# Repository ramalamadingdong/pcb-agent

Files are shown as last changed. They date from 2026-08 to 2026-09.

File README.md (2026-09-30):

# pcb-agent

Design a circuit board end to end with an agent. Parts, netlist, placement,
routing, gerbers a fab will build. You review, it does the work.

<p align="center">
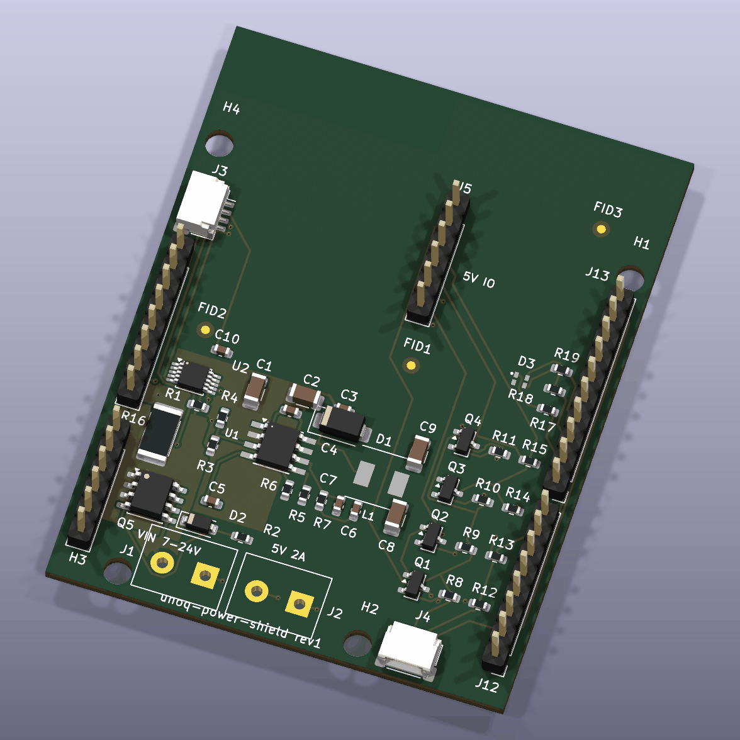
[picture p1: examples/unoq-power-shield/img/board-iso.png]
3D render of the example board: a UNO Q power and I/O shield, 49 components on four layers
  
</p>

<p align="center"><em>The example board —
<a href="examples/unoq-power-shield">examples/unoq-power-shield</a>, 49 components
on four layers, routed to 0 unconnected and 0 clearance violations. A KiCad render
of the design files in this repo; <strong>no physical board has been
fabricated</strong>.</em></p>

The method: **the design lives in a CSV, not in KiCad.** One row per pin.
Scripts build the schematic and the board from it. Nothing in the KiCad files
is edited by hand — to change the circuit you edit a row and rebuild. Then
five levels of checking, the last of which parses the exported gerbers,
because the gerbers are what the factory builds.

Written up in full at
[mouro.ai/blog/pcb-design-with-ai](https://mouro.ai/blog/pcb-design-with-ai/)
— why the CSV is the source of truth, the tool behaviour each pass exists
to survive, and what the example board cost to finish.

**New here? [docs/end-to-end.md](docs/end-to-end.md)** is the whole path in
one page: install, prove the toolchain on the example, then your own board
from an idea to a fab package.

## Status: passes landed, example board unproven

The build passes are in `scripts/build/` and the whole pipeline runs end to
end against the example board: netlist → schematic (clean round-trip diff) →
board → netclasses → floorplan → holes → zones/fanout → freerouting →
completion → fab export → checker. As of 2026-08-30 the example has passed
its pre-order gates — **0 unconnected, 0 clearance violations** across 5
identical DRC runs, `validate_gerbers` 14/0, `check_placement` 5/0, ERC
clean, every residual DRC item explained in its `rev-1-plan.md` ledger — but
**no physical board has been fabricated yet**. Until one comes back and powers on, treat
`examples/unoq-power-shield` as a pipeline exercise, not a verified
reference design.

**2026-09-30: three defects found and fixed, example rebuilt.** New gates
caught three real defects that the earlier gates had passed:

- **J4 (Qwiic) was rotated 180°.** Its socket opened into the board.
  `check_placement` now derives which way a connector faces from its
  rotation. J4 is at 0° now.
- **16 pads on eight rotated passives lay along the part axis.**
  `fix_pad_angles --check` now gates on it.
- **`finish_routes` laid redundant copper on already-routed nets.** Its
  connectivity model never joined a segment's two ends. That is fixed, and
  roughly 200 redundant segments and 69 vias are gone.

The example was rebuilt from `netlist.csv` in the pinned container.
`make check` passes every gate:

- ERC: 0 errors.
- Pad angles: all correct.
- DRC ×5: 13 errors, all in the `[[drc.accept]]` ledger with reasons, 0
  unconnected, identical in every run.
- `check_placement`: 11/0.
- `validate_gerbers`: 15/0, including the IPC-D-356 netlist against
  `netlist.csv`, 159/159 pins.

It is still **unfabricated**. See `rev-1-plan.md` for what remains at order
time.

If you want only the fab-output checker, it stands alone with no dependencies
at [gerber-check](https://github.com/ramalamadingdong/gerber-check).

Platform honesty: developed and verified on Linux (WSL) — the container
path, the clean-box doctor advice, and the whole pipeline. **macOS is
untested**: `doctor.py`'s KiCad.app python path was written from
documentation, not a Mac, and is the most likely thing to be wrong. If you
hit it, an issue with your `doctor.py` output is gold.

## Setup

```bash
git clone https://github.com/ramalamadingdong/pcb-agent && cd pcb-agent
python3 scripts/doctor.py
```

The doctor names every missing piece and the fix for your OS. Five things have
to line up — KiCad (9 or 10, **matching the major your boards use**: a KiCad 9
pcbnew returns None loading a KiCad 10 board, no error), KiCad's bundled
Python, a JVM matching your Freerouting, the Freerouting jar, and `uv` — and
each fails in a way that wastes an afternoon if you don't know what you're
looking at.

### Or: the container

The headless stages run in a container instead, so KiCad, Java and
Freerouting never need installing by hand:

```bash
make setup     # builds the pcb-agent image; fetches the pinned Freerouting
               # jar to tools/ for native runs, checksum-verified
make doctor    # reports what the container satisfies
make build route export check   # run in-container automatically when the
                                # image exists (BOARD_DIR picks the board)
```

`./run.sh <cmd>` runs any command in the container with the repo mounted at
/work, as your uid/gid. You still install KiCad natively to *look* at the
board — the container has no GUI (the one X11 artifact inside is xvfb, a
virtual framebuffer that exists solely because Freerouting 1.9.0 asks for a
screen size it never uses). The base image is digest-pinned (`KICAD_BASE` in
the Makefile) and must match your native KiCad major; the doctor warns on
drift. kicad/kicad images are linux/amd64 — Apple Silicon runs them under
emulation.

Then, in Claude Code:

```
/plugin marketplace add aklofas/kicad-happy
/plugin install kicad-happy@kicad-happy
```

Eleven KiCad skills by Andrew Klofas — datasheet extraction, EMC, SPICE,
sourcing from DigiKey, Mouser, LCSC and element14, fab prep for JLCPCB and
PCBWay. MIT. This is the install that matters most.

## Use

```
/new-board     an idea, interviewed into a cited plan and a netlist.csv
/build         netlist.csv -> schematic -> board -> placement -> zones -> silk
/route         snapshot -> Freerouting -> DRC x5 -> gerbers
/check         ERC, pad angles, DRC x5, placement, and the fab package, all gated
/improve-placement   look at where routing got stuck, try floorplan edits,
               keep only what a rebuild + re-route measures as better
/doctor        is this machine able to run any of it
```

`/new-board` stops twice for your sign-off: once after the interview, once
before it writes the netlist. Those stops are the safety story. An
idea-to-board prompt with no stops will produce sixty confident rows of
hallucinated pin numbers and you won't find out until the boards arrive.

The whole path, install to fab package:
[docs/end-to-end.md](docs/end-to-end.md). From netlist to fab package for
your own design, in more detail:
[docs/your-own-board.md](docs/your-own-board.md) — the board.toml sections,
the placement loop, and the traps this repo already paid for.

## What's here and what isn't

Working now:

- **`scripts/validate_gerbers.py`** — the level-4 checker. Reads exported
  gerbers and drill files as text. No dependencies, no install, doesn't need
  KiCad. Runs on any fab package from any tool. See below.
- **`scripts/build/check_placement.py`** — the board-level checker, and the
  other half of `make check`. Two things the gerber checker structurally
  cannot see: whether every `[[connectors]]` part can actually be **plugged
  into** (mating face reaches the outline, corridor for plug and cable clear —
  mounting holes inflated to the *screw head*, which is the thing actually in
  the way and which no courtyard in the file describes), and copper in a
  keepout named by object (`R12 pad 2`, `via GND at 41.20,18.05`) instead of
  by aperture. Runs in about a second off the board file, so a floorplan
  mistake surfaces while the floorplan is still what you are editing, not
  fifteen minutes later in the fab package.
- **`scripts/build/drc_sample.py`, `erc_check.py`**: levels 1 and 2 as
  gates, not reports. DRC runs 5×, and anything unexplained in any run fails.
  The explanations live in `board.toml` as `[[drc.accept]]` entries, each
  with its reason. An entry that stops matching fails too. Connectivity
  parity (the board's nets against the schematic) is gated even though KiCad
  ships it as a warning.
- **`check_netlist`** in `validate_gerbers.py`: level 0 on what ships. The
  export includes an IPC-D-356 netlist (the file a fab's electrical test
  probes against), and the checker holds it to `netlist.csv` pin by pin.
- **`scripts/build/render_review.py`** (`make render`): a PNG per copper layer
  with the ratsnest in red and completion-pass copper in orange, for level 3
  and `/improve-placement`. **`score_route.py`** (`make score`): one
  comparable score for a routed board, measured, never read from the
  router's log.
- **`scripts/doctor.py`**: environment preflight.
- **`CLAUDE.md`** — the rules. This is what keeps an agent from undoing the
  work: don't edit board files, fixes go in the pipeline, every pass
  idempotent, don't trust a tool's self-report, get the document.
- **`commands/`**: the six slash commands.
- **`templates/`** — `netlist.csv` schema and a commented `board.toml`.

Also here now:

- **`scripts/build/`** — the build passes, ported from the pipeline that
  shipped real boards. They encode specific tool behaviour discovered by
  getting boards back broken — `repair_pads` restoring rotation as well as
  position, the net-table assertion after every board write, the
  four-spacing fanout check, `silk_finish` repositioning every refdes —
  with the comments explaining why each guard exists.

Not here yet:

- **An example board that has been powered on.** `examples/unoq-power-shield`
  has a cited plan and netlist, but until one is built and brought up it is a
  reference design nobody has verified.

## The gerber checker on its own

Useful even if you never adopt the rest:

```bash
python3 scripts/validate_gerbers.py --init      # writes board.toml
python3 scripts/validate_gerbers.py ./fab/
```

Catches what passes ERC, passes DRC, passes every fab export, and still ships
a broken board:

| Check | Why nothing else sees it |
| --- | --- |
| Signal traces on a layer you declared a plane | DRC doesn't know it's a plane. Breaks the reference for anything routed over it. |
| Power nets at default trace width | Generated netclass patterns (`VCC*`, `VDD*`, `+*V`) match none of the usual net names. Nothing errors, the traces just come out thin. |
| Missing mounting holes | Not netlist objects. Nothing emits them unless you write the pass. |
| Silkscreen past the board outline | The fab clips it. Boards print bare. |
| Fiducials missing, collinear, or in a keepout | Keepout rules ban pours, tracks and vias — not pads. |
| Too few thermal vias under an exposed pad | No rule covers "enough". |
| RF trace over budget | Nothing measures it. |

Rules you don't configure report `SKIP`, not `PASS`. A check you haven't
written isn't a check that passed.

Export with X2 attributes on — net names and fiducial tags ride in those, and
without them the net-aware checks go blind.

## Scope

This gets you to a package a fab will build and a written reason behind every
choice in it. Respins in hours instead of days, because the fixes are in code.

It doesn't replace bring-up. Done and clean and fabricated isn't the same as
working.

## Credit

- [kicad-happy](https://github.com/aklofas/kicad-happy) — Andrew Klofas, MIT
- [kicad-tools](https://github.com/rjwalters/kicad-tools) — RJ Walters, MIT
- [Freerouting](https://github.com/freerouting/freerouting)
- [KiCad-AI-Assistant](https://github.com/paul356/KiCad-AI-Assistant) (MIT,
  © 2025 Lama Al Rajih): `render_review.py`'s per-layer panels and MST
  ratsnest follow the approach of its board renderer. The ideas are
  borrowed; no code was copied.
- [KiCad](https://www.kicad.org/)

GPL-3.0 — the build passes import `pcbnew`, which is GPL-3.0, and now that
they've landed the repo follows.
[gerber-check](https://github.com/ramalamadingdong/gerber-check) is pure
stdlib text parsing, links nothing, and stays MIT.

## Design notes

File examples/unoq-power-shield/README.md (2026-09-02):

# UNO Q power & I/O demo shield

<table>
<tr>
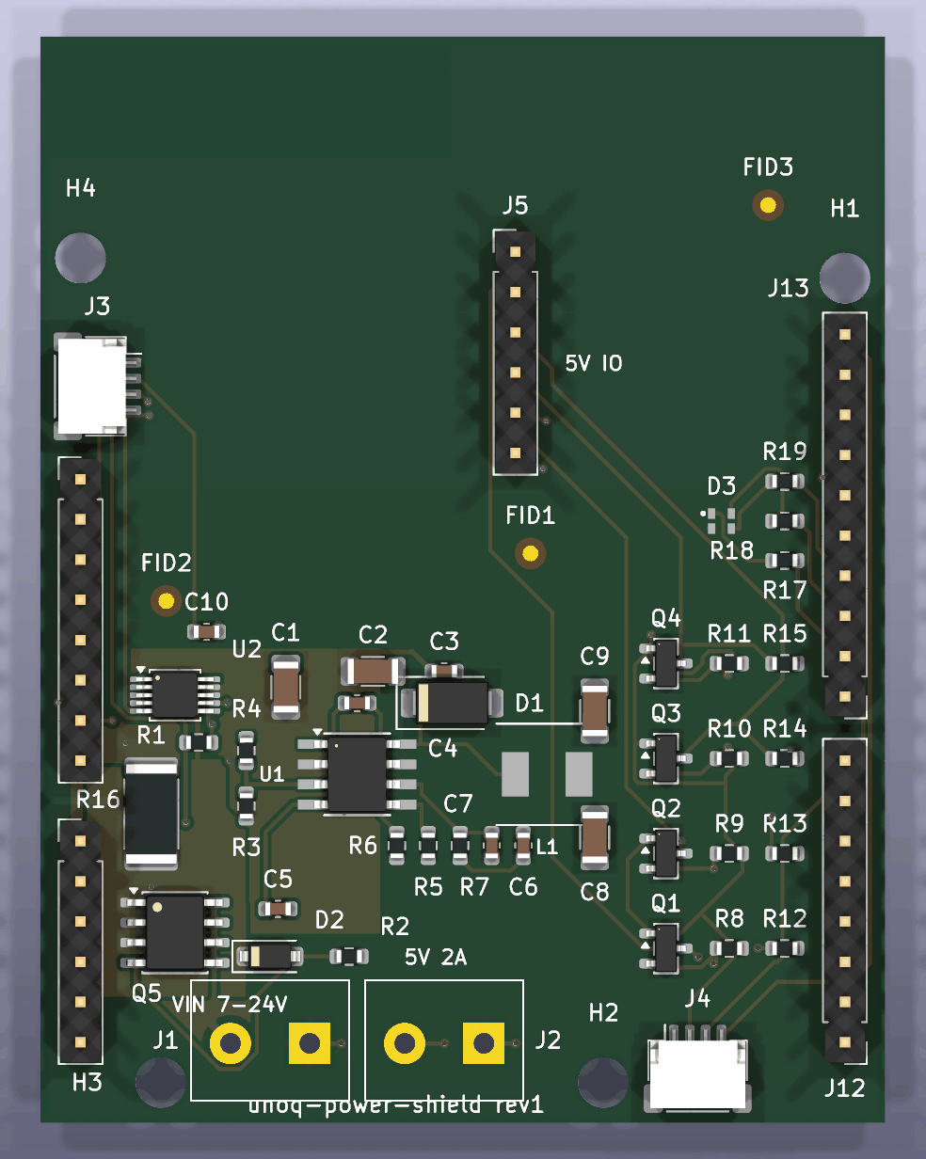
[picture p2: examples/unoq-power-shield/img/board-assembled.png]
Render of the board with every component placed
<td width="50%"></td>
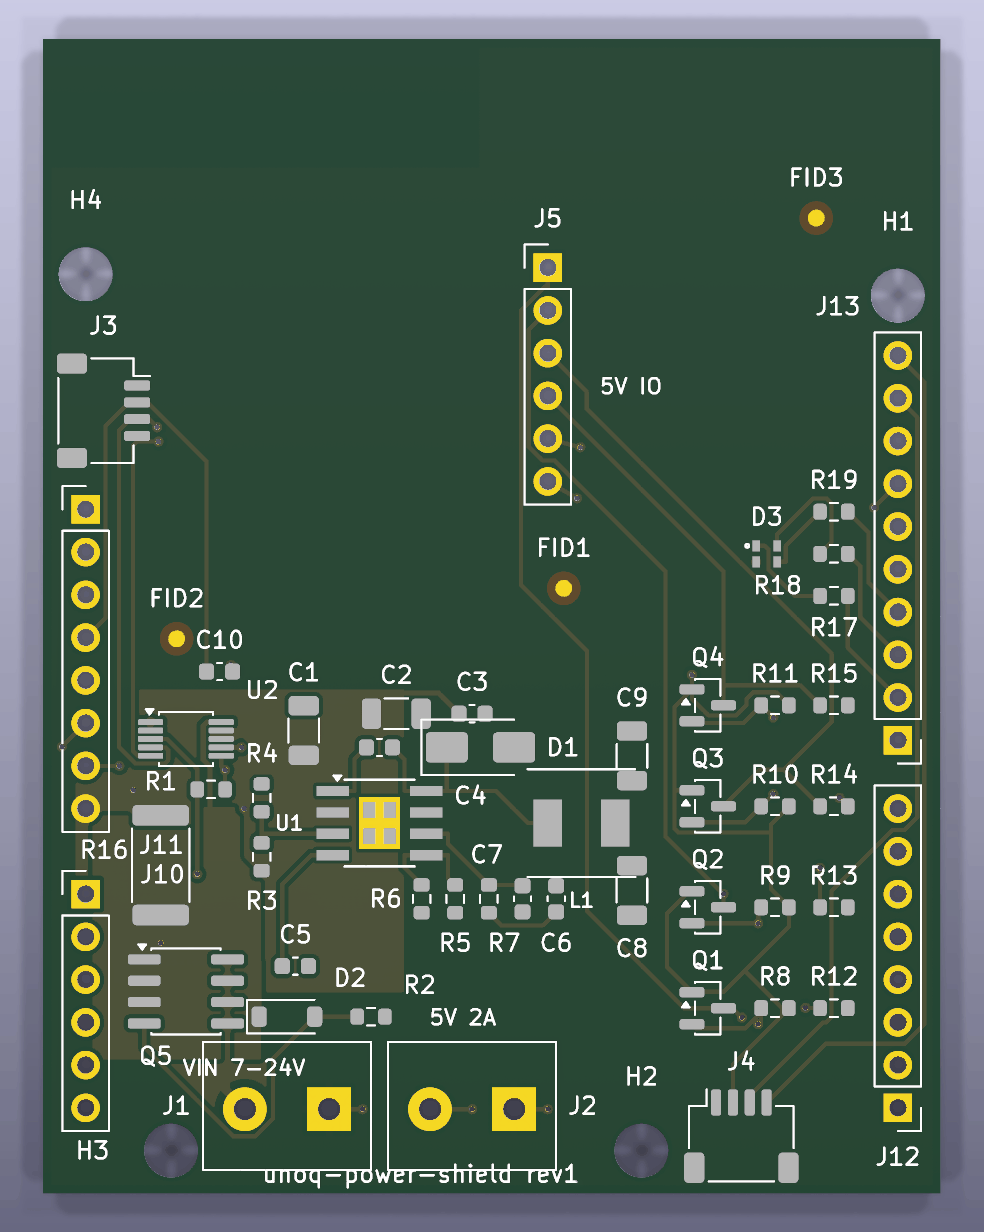
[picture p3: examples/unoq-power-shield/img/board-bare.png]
Render of the bare PCB with no components
<td width="50%"></td>
</tr>
<tr>
<td align="center"><em><strong>Populated</strong> — every footprint with its 3D
model. The four edge strips and J5 are drawn as plain male pin headers because
that is what the footprint's model is; the real parts are <strong>stacking</strong>
headers — female sockets on top, long tails passing down into the UNO Q — and
they ship <strong>DNP</strong> (see below), so an assembled board arrives with
those pads bare.</em></td>
<td align="center"><em><strong>Bare</strong> — the PCB the fab builds from the
gerbers: four-layer copper, mask, silk, and the three X2-tagged fiducials the
assembler's vision system needs.</em></td>
</tr>
</table>

**Status: UNBUILT.** No physical board of this design has been fabricated
or powered on yet. Until one has, treat this as a reference for exercising
the pipeline, not a verified design.

The *design* has passed its pre-order gates (2026-08-30): routed with
**0 unconnected** and **0 clearance violations** across 5 identical DRC
runs, `validate_gerbers` 14/0, ERC clean, every BOM line in stock. The 17
residual DRC items are all form-factor or courtyard-graze artifacts,
individually explained in the ledger in [rev-1-plan.md](rev-1-plan.md).
Passing gates is not the same as working hardware — the UNBUILT warning
above stands until a board has been powered on.

**The stacking headers ship DNP** — the assembled board cannot plug into
anything until you solder a stacking header set into the four plated hole
strips. Any classic Arduino R3 stacking kit fits: SparkFun PRT-11417 or
Adafruit #85, about **$2**. This is deliberate: assembly houses don't stock
stacking headers, and a flush-soldered normal header would make the shield
unstackable.

The example board for this repo — the design a first-time user builds
**before trusting the pipeline with their own board**. If this builds,
routes, checks, and comes back from the fab working, the pipeline works.
That is all it proves: it says nothing about whether any *other* design is
right, and it is not a product.

## What it is

A shield for the [Arduino UNO Q](https://docs.arduino.cc/hardware/uno-q)
(classic UNO outline, stacking headers):

- **Screw-terminal VIN, 7–24 V** — the UNO Q's own DC input range. Feeds
  the Q's VIN pin and a local TPS54331 buck making 5 V for shield loads,
  behind reverse-polarity protection (the terminal a first-timer wires
  backwards).
- **INA226 high-side monitor** on the VIN rail, upstream of everything, so
  the stack reports its **own total consumption** over I²C (address 0x40,
  on D20/D21; ALERT on ~D3).
- **Four bidirectional level-shift channels** (BSS138 + 10 k) between the
  headers and 5 V peripherals, on D2/D4/D7/D8. **The UNO Q's headers are
  3.3 V logic, not the classic UNO's 5 V** — wiring 5 V gear straight in is
  the most common way this board gets damaged, and this circuit is the fix.
  **Signalling limit: ~300 kHz.** The 10 k pull-ups against ~30 pF of load
  give ~0.3 µs rise times: fine for GPIO, buttons, slow UART, and 100 kHz
  I²C-style traffic; **not for SPI above ~300 kHz and not for NeoPixels**
  (WS2812 timing needs edges these channels cannot produce). That is a
  documented property of the classic BSS138 shifter, not a defect.
- **Qwiic passthrough** (2× JST-SH, daisy-chain) on the same I²C bus.
- **RGB status LED** on ~D9/~D10/~D11, active-low, for sketches to drive.

Design record: [rev-1-plan.md](rev-1-plan.md) — every requirement cited to
Arduino's own documents, every part checked against the JLCPCB library,
every number with its arithmetic shown. Rules: [board.toml](board.toml).

## What it teaches

Each `board.toml` rule exists here for a visible physical reason:

| Rule | Why it's real on this board |
| --- | --- |
| thermal vias | the buck's exposed pad is its only real heatsink |
| power trace width | VIN carries up to 4 A; IPC-2221 sets the number |
| mounting holes | all four fixed by the UNO pattern — extracted from Arduino's own drill file |
| planes | solid ground under a switching converter |
| keepout | the UNO Q's Wi-Fi antenna is directly under the board's top-left corner — copper there detunes it |
| fiducials, X2-tagged | assembly needs them, and untagged ones are invisible to gerber-level checking |

## What it costs (estimate, 2026-08)

- 4-layer PCB, 5 pcs: ~$8–15
- JLCPCB SMT assembly (2–5 boards): setup ~$25, ~10 Extended-part feeder
  fees ~$30, parts ~$2.5/board, THT screw terminals hand-solder fee
- **Ballpark: $70–90 for a small assembled batch**
- Stacking headers are DNP — fit any Arduino stacking-header kit (~$2)

## Power behavior

| Supply | Result |
| --- | --- |
| USB-C only | UNO Q runs; shield 5 V rail is off (needs VIN) — by design |
| VIN only | everything runs; the Q is powered through its VIN pin |
| both | fine — the Q diode-ORs internally; the shield never drives the 5 V or 3V3 header pins |

## Attribution

The UNO Q facts in this design — pinout, electrical limits, mechanical
coordinates, antenna location — come from Arduino's official documents and
CAD files for the UNO Q (ABX00162), © Arduino SA, licensed
[CC BY-SA 4.0](https://creativecommons.org/licenses/by-sa/4.0/):
datasheet, full pinout, schematics, and fab data, copies in
[docs/datasheets/](../../docs/datasheets/). The antenna keepout and
hole/header coordinates were extracted from the gerber and NC-drill files
Arduino publishes there. This example's own design files are MIT like the
rest of the repo; the CC BY-SA attribution above covers what was derived
from Arduino's documents.

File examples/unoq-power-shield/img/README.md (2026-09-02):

# Board renders

Generated from `../unoq-power-shield.kicad_pcb` with `kicad-cli pcb render`.
Regenerate after any layout change — these are pictures of a board file, and a
stale one is a lie about the current design.

**Run these against a NATIVE KiCad, not the container.** The `kicad/kicad`
base image ships no 3D model packages, so a render from inside the container
silently comes out bare — every part missing, no error. That failure mode is
also the trick used for `board-bare.png` below: point the model variable at a
path that doesn't exist and nothing resolves.

```bash
BRD=examples/unoq-power-shield/unoq-power-shield.kicad_pcb
IMG=examples/unoq-power-shield/img

# board-iso.png — populated, isometric (the repo's hero shot)
kicad-cli pcb render -o $IMG/board-iso.png --width 1200 --height 1200 \
  --side top --quality high --background opaque --rotate "-22,0,-18" --zoom 0.85 $BRD

# board-assembled.png — populated, straight down
kicad-cli pcb render -o $IMG/board-assembled.png --width 1000 --height 1260 \
  --side top --quality high --background opaque --zoom 0.95 $BRD

# board-bare.png — same framing, no components
kicad-cli pcb render -o $IMG/board-bare.png --width 1000 --height 1260 \
  --side top --quality high --background opaque --zoom 0.95 \
  -D KICAD10_3DMODEL_DIR=/nonexistent $BRD
```

`-D KICAD10_3DMODEL_DIR` must match the major version the board file
references (grep the `.kicad_pcb` for `3DMODEL_DIR`) — on KiCad 9 boards the
variable is `KICAD9_3DMODEL_DIR` and the override silently does nothing under
the wrong name, giving you a populated render where you wanted a bare one.

The committed PNGs are quantized to a 256-colour adaptive palette (~65%
smaller, visually identical on these flat-shaded renders).

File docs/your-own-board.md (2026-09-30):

# Your own board, start to fab package

The example (`examples/unoq-power-shield/`) is the reference
implementation — every section named here exists there, filled in with
cited values. Build it once before trusting any of this with your own
design. This page is the map; the example is the territory.

## 0. Preflight

```bash
python3 scripts/doctor.py     # names every missing piece and the fix
make setup                    # or install natively per the doctor
```

## 1. Plan and netlist — `/new-board`

Run the `/new-board` command (in Claude Code) or follow
`commands/new-board.md` by hand. It ends with two artifacts in your board
directory: a plan doc with every choice cited, and `netlist.csv` — one row
per pin, every pin of every IC. The rule that governs it: **no pin number
that didn't come from a document read in-session and cited.** The
schematic generator's round-trip diff will hold you to the CSV; nothing
holds the CSV to reality except that rule.

## 2. The build config — board.toml, section by section

One file drives both the build passes and the gerber checker. **One
coordinate frame everywhere: origin at the board's bottom-left corner,
X right, Y up** — the frame of a drill file exported with the aux origin
at that corner. `export_fab.py` pins the aux origin there, so your
config's rectangles and the checker's gerber coordinates are the same
numbers. Never write a KiCad page coordinate into board.toml.

| Section | Consumed by | What it is |
| --- | --- | --- |
| `[board]`, `[frame]` | checker + passes | name; the outline bbox every coordinate rule is anchored to |
| `[build]` | create_pcb | width/height/layers/title/revision |
| `[libs]`, `[[libs.symbols]]` | make_libs, generate_schematic | project library name, vendored-footprint dir, and pin tables for ICs with no stock symbol — pin numbers from the datasheet's land drawing |
| `[parts.<REF>]`, `[[part_rules]]` | make_libs, generate_schematic | symbol + footprint per refdes (rules by prefix for jellybeans, per-ref overrides for everything else) |
| `[[floorplan.place]]` | floorplan, place | hand placements, locked; see the loop below |
| `[direct]` | direct_connect | `overlap_mm` / `clearance_mm` for `Direct`-tagged netlist rows: parts placed pad-on-pad against a pin already on their net. Every pair shows up in DRC as an expected `courtyards_overlap`, listed in the pass's JSON; the DRC gate accepts exactly those pairs (tagged part against one of its own netlist targets) without a ledger entry |
| `[mounting_holes]`, `[fiducials]` | passes AND checker | positions place them; count/diameter checks them in the gerbers |
| `[[keepouts]]` | add_keepouts, silk, router passes, both checkers | one rectangle feeds the rule area, the silk dodge, the router fences, the board check and the gerber check |
| `[[connectors]]`, `[connector_footprints]`, `[connector_policy]` | check_placement | every part a person plugs into. Edge connectors: the room the plug and cable need, **and which way the part actually faces**, derived from its rotation against the footprint's datasheet opening. Vertical/stacking headers: a clear access ring on the mating side. An undeclared J/P/CN/USB ref fails |
| `[drc]`, `[[drc.accept]]`, `[[erc.accept]]` | drc_sample, erc_check | the ledger of explained violations: exact refs plus a reason. Anything else fails route and check, and so does an entry that stops matching |
| `[[zones.pour]]`, `[layers] planes` | zones, export_dsn, checker | pours; plane layers are routing-banned and gerber-checked for stray tracks |
| `[nets.power]` | apply_netclasses + checker | patterns pin nets to the power netclass BY NAME; `min_width_mm` is the checker floor; `plane_fed` exempts short pad-escape chains on plane-backed nets |
| `[[fanout.thermal_vias]]` | fanout | vias at named pads — exposed pads, and any pour island the DRC shows floating |
| `[route]`, `[route.completion]` | route chain | widths, via, clearance. **Set completion `clearance_mm` equal to your DRC minimum** or every completion link lands as a violation |
| `[fab]` | export_fab | output naming; optional JLC BOM/CPL generation |

Three traps that cost this repo real debugging time, so you don't pay
them again:

- **Footprints come from land drawings, not text**, and a vendored
  `.kicad_mod` must be strict KiCad syntax — `(layer …)` goes *outside*
  `(stroke …)`. The lenient parser in the toolchain will accept the wrong
  nesting and pcbnew will reject the whole board with an error pointing
  at an unrelated line.
- **Pin-header strips run downward from pin 1** at rotation 0 (KiCad Y
  runs down, our frame runs up). Check where pin N lands before locking a
  connector next to something else. The example shorted an LED to a
  header pin this way.
- **Netclass clearance must equal your DRC minimum.** A smaller netclass
  clearance reaches the DSN, freerouting routes to it, and every squeeze
  becomes a DRC violation you then chase one at a time.

## 3. The build loop

```bash
make build BOARD_DIR=path/to/yours     # libs → schematic → board → place → zones → marks → silk
```

Placement is a loop, not a step. After every build:

```bash
./run.sh kct placement check path/to/yours/your-board.kicad_pcb
```

Fix the **errors** by editing `[[floorplan.place]]` coordinates and
rebuilding — the pass is idempotent, re-runs are cheap. The example went
26 → 10 → 6 → warnings-only over four iterations; that's normal, not
failure. Warning-class items (edge-connector overhang, screw-head
courtyard grazes) are judgment calls the report describes precisely.

## 4. Route and check

```bash
make route BOARD_DIR=path/to/yours     # snapshot → freerouting → completion → DRC ×5, gated
make export BOARD_DIR=path/to/yours    # gerbers, drill, pos, IPC-D-356
make check BOARD_DIR=path/to/yours     # ERC, pad angles, DRC ×5, placement, fab package
make render BOARD_DIR=path/to/yours    # review/*.png: look at it
```

Read the route JSON line, not the router's mood:
- `segments_after_router` must be well above `segments_before`. A silent
  no-op is detected and fails, but look anyway.
- `unrouted_after_router` is what Freerouting left, counted by pcbnew
  before completion.
- `unfixed` names nets the completion couldn't finish.
- The `drc` block lists every violation not in your `[[drc.accept]]` ledger.
  The route fails if there is any.

The first route of a new board will fail the DRC gate. That is expected.
For each violation, either fix it (almost always in the floorplan) or,
when it is a real exception, add a `[[drc.accept]]` entry naming its refs
and the reason a reviewer would accept.

Nets the completion leaves unfixed usually mean a congested corner:
give the parts room in the floorplan rather than fighting the router.
`/improve-placement` does that as measured trials. It looks at the render,
proposes floorplan edits, rebuilds and re-routes each one in a scratch
copy, and keeps only what `score_route.py` measures as better. Then it
stops for your sign-off.
A DRC "zones not connected" usually means a pour island holding a pad
with no via — `island_diag`-style inspection names the pad; give it a
`[[fanout.thermal_vias]]` entry.

## 5. Gates

Your plan doc ends with the gate list. Nothing ships until:

- schematic round-trip diff clean (the build fails otherwise)
- ERC clean, DRC ×5 with zero errors and explained warnings: `make check`
  enforces both, against the ledger in board.toml
- `make check` green — SKIPs investigated, not counted
- every ledger entry's reason re-read. An acceptance is a claim.
- every part re-verified in stock at order time
- the exact ordered files committed byte-for-byte

Anything you catch by hand on the way becomes a line in board.toml, so
the checker catches it next time. That is the whole point.

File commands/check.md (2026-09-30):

---
description: Validate the schematic, the board and its exported fab package against board.toml. Run after every export, and always before ordering.
---

`make check` runs five gates. Each one runs even if an earlier one fails,
and `check` fails at the end if any did. They read different artifacts and
fail differently, so no one of them passing excuses skipping another.

| gate | reads | catches |
| --- | --- | --- |
| `erc_check.py` | schematic | ERC errors not in `[[erc.accept]]` (level 1) |
| `fix_pad_angles.py --check` | board | pads not at footprint rotation + library angle: the "pads on a rotated part lie along its axis" fault |
| `drc_sample.py` | board (a filled **copy**) | DRC ×5: any error not in `[[drc.accept]]`, any unconnected item, any parity issue about connectivity, any GUI exclusion, any stale ledger entry (level 2) |
| `check_placement.py` | board | connectors a person can't use, and copper in keepouts |
| `validate_gerbers.py` | the fab package, as text | what the fab will plot, **including the IPC-D-356 netlist held to netlist.csv** (levels 0 and 4 on what ships) |

(`make erc`, `make drc` and `make check-placement` run one gate each.)

- **`check_placement.py`** reads the BOARD through pcbnew and can name what
  it found (`R12 pad 2`, `via GND at 41.20,18.05`). For every
  `[[connectors]]` part it checks:
  - **which way it actually faces.** This is derived from its rotation by
    fitting the part's pads to the library footprint, then comparing the
    footprint's datasheet opening (`[connector_footprints]`) with the
    declared face. A connector rotated 180° at the right edge passes every
    clearance test while its opening points into the board.
  - **whether its mating face reaches the outline,** and whether the
    corridor the plug and cable need is clear. Mounting holes count at the
    screw head's size.
  - **for vertical and stacking headers,** whether an access ring on the
    mating side is clear.
  - **whether every connector-looking ref (J/P/CN/USB) is declared** at all.
- **`validate_gerbers.py`** reads the exported bytes as text, with no
  dependencies and no KiCad. It cannot name anything beyond apertures and
  flashes, but those are the bytes the fab will plot.

A PASS on the board and a FAIL on the package means the **export** moved
something. That case is why both exist.

Report every line. Then:

- **Any FAIL:** fix it in the pipeline, never in the board file. Re-run the
  build, re-export, re-check. A fix made by hand is wiped by the next
  rebuild. A connector failure is usually a floorplan fix
  (`[[floorplan.place]]`), not a routing one.
- **A ledger entry (`[[drc.accept]]`, `[[erc.accept]]`, `accept_blockers`)
  is a claim, and it needs a reason a reviewer would accept.** Never add one
  just to turn a gate green. If you can't write down why the violation is
  fine, it isn't.
- **Any SKIP:** that is a check nobody wrote. Say so plainly. A rule you
  never configured is not a rule that passed.
- **Warnings** (DRC silk, parity lib-nickname mismatches, ERC footprint
  links) are printed but don't gate. Read them anyway. Don't wave off a
  warning because a gate stayed green.
- **All PASS:** good, and still not evidence the board works. Done and clean
  and fabricated isn't the same as working.

Then look at the board: `make render` writes one PNG per copper layer to
`review/`. Read them. That's level 3, and it's the one to trust least,
because you'll see what the build was supposed to do. Look for what it did.

If the user found something by hand that the checker missed, add it to
`board.toml` now, while you know what it was. That is how this file earns its
keep.

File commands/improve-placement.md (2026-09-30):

---
description: Look at where routing got stuck, propose floorplan edits, and keep only the ones a rebuild and re-route prove better. Stops for sign-off before touching the real board.toml.
---

The picture proposes and the measurement decides. You look at renders of
the board and propose changes to its **floorplan**, meaning the
`[[floorplan.place]]` x / y / rotation / side and the `[floorplan] anchors`
in `board.toml`. The pipeline rebuilds and re-routes each proposal, and
`score_route.py` judges it. You never draw copper and never edit a KiCad
file. A proposal that scores worse is logged and dropped, however good it
looked.

Budget: **3 trials** unless the user gives another number. Each one is a
full build plus route, about 15 minutes, most of it the placement loop.

## 0. Baseline

The board must already be built and routed (`make build route`), so that
`$(BOARD_DIR)/build/route.json` exists.

```bash
make render      # review/<board>-all.png, one PNG per copper layer, review/kicad/
make score       # build/score.json -- the number to beat
cp $BOARD_DIR/build/score.json $BOARD_DIR/build/score-baseline.json
```

Read every PNG in `review/` with the Read tool: the whole board first
(`-all`), then each layer. What the colours mean:

- **red lines:** nets still in pieces, with the net name on the line;
- **orange copper:** nets Freerouting left that the completion passes
  (finish_routes) finished. This is where the router struggled;
- **magenta:** segments not at 45 degrees, which the completion passes drew.

Also read `route.json`'s `unrouted_after_router`. That is pcbnew's count of
what Freerouting left, taken before completion, and it is the number that
tells you where the router struggled.

## 1. Propose, at most 3 edits per trial

For each edit, write down the reason in terms of the picture: "the 3V3_UNO
ratsnest crosses the whole board from J11 to Q1-Q4, so move the level
shifters toward J11", or "R3/R4 sit in U1's escape path, and 6 orange nets
detour around them". Good edits shorten the red and orange runs, uncross
them, or open a channel. Only move parts the floorplan already places, or
add a part to `[[floorplan.place]]` with a reason.

**Never propose a change that `check_placement` would fail.** Connectors
keep a face that reaches their edge and a rotation that points their
opening at it (the check derives the facing from the rotation, see
`[connector_footprints]`). Keepouts stay clear. The score ranks any
placement failure below every routing result, so a "better-routing"
trial that rotates a connector inward loses automatically. Don't spend
a trial on one.

## 2. Run the trial

Never edit the real `board.toml` during a trial. Copy the board's SOURCE
files (not its build outputs) into a trial directory and edit the copy:

```bash
T=$BOARD_DIR/build/trials/t1            # build/ is gitignored and cleaned
mkdir -p $T
cp $BOARD_DIR/board.toml $BOARD_DIR/netlist.csv $T/
cp -r $BOARD_DIR/<[libs] vendor_dir> $T/      # e.g. footprints.pretty
cp $BOARD_DIR/bom.csv $T/ 2>/dev/null || true
# edit $T/board.toml: only the floorplan entries you proposed
make build route render score BOARD_DIR=$T NAME=<board name> \
     BASELINE=$BOARD_DIR/build/score-baseline.json
```

`NAME` pins the file names to the real board's. Without it they would be
named after the trial directory.

The score line prints `better`, `worse` or `same`, and which component decided
it (placement, DRC, router_left, unfinished, vias, length, in that order).

## 3. Log every trial, kept or not

Append to `$BOARD_DIR/placement-trials.md`, which is committed and is the
record:

```markdown
## Trial N: YYYY-MM-DD
Edits:  J3 (3.6, 46.5, 270) -> (3.6, 40.0, 270); anchors += ["U2"]
Why:    <what you saw in which render>
Before: placement 0, drc 0, router_left 41, unfinished 0, vias 114, 1605.8 mm
After:  placement 0, drc 0, router_left 29, unfinished 0, vias 109, 1571.2 mm
Result: better (router_left 41 -> 29). Kept as the new baseline.
```

A worse trial is logged with the component that decided it and then
discarded. Its trial directory can be deleted. If a trial is better, its
score becomes the baseline for the next trial, and later trials build on
its `board.toml`.

## 4. Stop for sign-off

When the budget is spent, show the user:
- the diff between the real `board.toml` and the best trial's `board.toml`;
- the before and after score, and the log;
- the best trial's `-all.png` next to the baseline's.

**Do not write the winning edits into the real `board.toml` without an
explicit yes.** After the yes: apply exactly that diff, then run `make build
route export check` on the real board. The trial result was a measurement of
the trial, and the real board has to earn its own.

## What this is not

- It is not a router. It never places copper, and a picture is not geometry.
  Coordinates you propose come from `board.toml`'s frame (bottom-left
  origin, Y up), not from pixel positions in the render.
- It does not edit `netlist.csv`. Swapping equivalent pins is a netlist
  change with firmware consequences, and it is out of scope here.
- A trial that is better on one routing run may be luck, since Freerouting
  isn't deterministic. When a trial wins by a small margin (router_left
  within about 10 %), re-run `make route score` on it once before calling
  it better.

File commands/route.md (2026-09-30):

---
description: Route the board from the post-build snapshot with Freerouting, then export and validate the fab package.
---

Run `make route`. This starts from the snapshot, not from a live build, so
placement can be re-run without paying for a re-route.

Non-negotiables:

- **`-mt 1`.** Multithreaded optimisation makes clearance violations. Single
  threaded is usually also faster, because it stops when it stops improving.
- **Foreground.** Backgrounded, Freerouting opens the file and exits without
  routing.
- **Version pinned to your Java.**

Verify rather than trust:

- Count copper segments before and after the router call. Correct net list
  plus zero copper is a silent no-op, and its self-report won't say so.
- A pass reporting no violations while laying traces through other nets' pads
  is not evidence. `route.py` runs DRC five times (`drc_sample.py`), and
  **fails** on anything unexplained in any run: an error missing from the
  `[[drc.accept]]` ledger, an unconnected item, or a ledger entry that no
  longer matches. Fix the board. Add a ledger entry only for a real,
  explained exception, with its reason.
- `unrouted_after_router` in the JSON is what Freerouting left, counted by
  pcbnew before the completion passes. When it is large, the fix is usually
  placement: see `/improve-placement`.

Declaring an inner layer a plane costs a routing layer — expect a chunk of
nets unrouted after the first pass and finish them with a completion pass.

Then export and run `/check`. Fixes go in the pipeline, never in the board.

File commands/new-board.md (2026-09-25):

---
description: Turn a plain-language board idea into a cited requirements doc and a netlist.csv the build pipeline can compile. Use at the start of any new board or major revision.
---

# /new-board

The user has an idea for a circuit board. Your job is to turn it into two
artifacts the pipeline can build from:

- `docs/rev-<N>-plan.md` — scope, requirements, part choices, capacity math,
  and the list of checks that must pass before anyone orders
- `netlist.csv` — one row per pin, every pin of every IC

You do **not** touch KiCad. You do not run the build. Those come after, and
only once a human has signed off on the plan doc.

## The rule that governs everything here

An LLM's memory of a pin map is a guess that looks like a fact.

Every pin number, every bus address, every electrical limit you write down
must come from a document you actually read in this session — a datasheet
PDF, a vendor reference design, a distributor page — and must carry a
citation. If you cannot cite it, you do not know it. Say so and stop.

Copy every datasheet you use into `docs/datasheets/` so an upstream revision
can't silently change your geometry later.

---

## Phase 0 — Interview

Do not start designing. Ask, and wait for answers. The user has an idea in
their head; your first job is to get it out intact.

Ask about, in roughly this order:

1. **What does it do?** One paragraph, in their words.
2. **Is there firmware?** Existing repo, or written later? If it exists, get
   the path — it's the best requirements source you have.
3. **Power.** Battery or wall? Chemistry and capacity? USB-C charging? What's
   the peak current draw and from what?
4. **Interfaces.** What talks to what, and over what bus. What has to be
   exposed to the outside world — connectors, buttons, LEDs, antenna.
5. **Constraints.** Board size or an enclosure it must fit. Layer count.
   Assembly house and process. Budget per board and quantity.
6. **What must not go wrong.** The thing that would make them throw the
   batch away.

Ask what you need and no more. If the user gives you a detailed spec up
front, skip to Phase 1 and confirm your reading of it in one paragraph.

**Stop here and show the user your understanding before continuing.**

---

## Phase 1 — Requirements, cited

If firmware exists, read it before anything else. Write down what the
hardware has to provide, every line citing a file and line number:

- Bus addresses and which peripheral sits at each
- Clock rates, sample rates, baud rates
- Partition sizes and filesystem layout
- Which peripherals are behind compile-time flags, and are therefore optional

That last one is what makes a new board cheap. A headless code path means a
board with no display needs no new firmware, just a pin map.

If there is no firmware yet, derive the same list from the user's answers and
mark each line `ASSUMED` so it's obvious what hasn't been verified.

---

## Phase 2 — Architecture and parts

Propose a block diagram in prose first — what parts, what connects to what,
why. Get agreement before sourcing.

Then source. Use the `digikey`, `mouser`, `lcsc` and `element14` skills, and
check more than one; they don't agree.

For every significant part record:

- Part number, price, **stock and lead time**
- Why this part — tied to a specific requirement from Phase 1
- What you rejected and why
- The datasheet, downloaded to `docs/datasheets/`

Lead time is a real constraint, not a footnote. A part with more stock and a
22-week lead is worse than one with less stock available now. When a cheaper
part can serve, state exactly which capabilities the firmware actually uses
and confirm the replacement provides all of them — a swap that deletes parts,
a crystal, and a layout constraint is worth more than the unit price
difference.

---

## Phase 3 — The pass that earns its keep

A BOM with the right ICs on it is usually still missing everything that makes
them run. Read every datasheet against the proposed connection table and
check specifically for:

- **Charger load-share path.** Hang the system load off the battery pin and
  the charger reads load current as charge current, never terminates, and
  trickles the cell forever.
- **Battery sense divider**, if firmware reports a battery percentage.
- **RF front end and antenna connector** on any receiver.
- **Strap and mode pins** tied somewhere. Floating, the part comes up in the
  wrong interface mode and never answers.
- **Decoupling** per the datasheet, not per habit.
- **Pull-ups** on every open-drain bus, with the value calculated.

Then do the capacity math and write it down:

- Data rate against storage size → how long does it record before it's full
- Current against trace width (IPC-2221, state the copper weight)
- Dissipation against package thermal resistance
- Battery capacity against average draw → runtime

If any of these comes out badly, that's a design change, and it's cheaper now
than after the boards arrive.

**Stop here. Show the user the plan doc and get sign-off before writing the
netlist.**

---

## Phase 4 — netlist.csv

The schematic is not the source of truth. This file is. The KiCad project is
a build output.

```
Net,RefDes,Pin,PinName,Direct,Note
VBUS,J1,A4,VBUS,,USB-C receptacle
VBUS,U4,4,VDD,,charger input
VBUS,D1,A,Anode,,Schottky into VSYS
VBUS,C7,1,~,yes,"100 nF, pad touching a VBUS pin"
GND,J1,SH1,SHIELD,,"chassis, stitch to GND with 4 vias"
```

Rules:

- **Every pin of every IC gets a row.** No exceptions.
- **`NC` written out** where a pin is meant to be unconnected, with a note
  saying why. A missing row and an intentional no-connect must not look the
  same.
- **`Direct` is optional** and usually empty. Tag ONE pin of a part with
  `yes` and `direct_connect.py` finds the other pins already on that net and
  places the part with that pad touching one of them — no trace. `REF` or
  `REF.PIN` limits the search to that part or pin. Use it for decoupling
  caps on IC supply pins and TVS parts on connector pins. It can't be
  combined with `[[floorplan.place]]` for the same part, and a tagged part
  can't be another tag's target.
- **The note column carries the reason**, not a restatement of the pin name.
  Cite the datasheet page where the choice came from a document.
- Pin numbers come from the datasheet's land drawing, not its text. Where the
  two disagree, the drawing is what the factory builds — a chip antenna whose
  text says two terminals and whose drawing shows three pads ships dead if
  you trust the text.

When the file is written, hand off:

> `netlist.csv` is ready. Run the build to generate the schematic. The
> round-trip check will fail the build if any net in the CSV didn't make it
> into the drawing.

---

## Phase 5 — The gate list

Close the plan doc with the checks that must pass before anyone orders. This
is the most important list in the document. At minimum:

- [ ] Schematic round-trip diff clean against `netlist.csv`
- [ ] ERC clean
- [ ] DRC run 5+ times, comparing which violations appear rather than the
      count — DRC isn't deterministic
- [ ] `validate_gerbers` PASS on the exported package
- [ ] Every part in stock at order time, re-verified
- [ ] The exact ordered files saved byte-for-byte

Add board-specific gates from Phase 3. Anything you found by hand becomes a
line in `board.toml` so the checker finds it next time.

---

## What you must not do

- **Don't edit KiCad files.** They're s-expressions full of coordinates.
  Being slightly wrong looks exactly like being right, nothing errors, and
  you get a broken board. Change a CSV row and rebuild.
- **Don't fix anything in the board file.** Fixes go in the pipeline. The
  next rebuild wipes anything done by hand.
- **Don't assume generated defaults match your names.** Netclass patterns,
  layer names, rotation conventions. Nothing errors; the output is just
  wrong.
- **Don't wave off a warning.** That's swapping a measurement for an
  assumption.
- **Don't skip a stop point** because the user seems in a hurry.

## What this does not give you

A plan and a netlist, not a working board. Done and clean and fabricated
isn't the same as working. This gets you to a package a fab will build and a
written reason behind every choice in it. Bring-up is still bring-up.

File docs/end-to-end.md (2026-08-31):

# End to end: from nothing installed to a fab package

This is the whole path. An idea goes in, a package a fab will build comes
out, and an agent does the work at every stage while you review. The
method behind it is written up at
[mouro.ai/blog/pcb-design-with-ai](https://mouro.ai/blog/pcb-design-with-ai/).

Read the two paragraphs below before you start. They are the difference
between this working for you and this wasting your week.

**What is verified.** Linux and WSL, with Docker. That is where the
container path, the doctor's advice and the whole pipeline were developed
and run. **macOS is untested** — `doctor.py`'s KiCad.app python path was
written from documentation, not from a Mac. Native Windows is not a path;
use WSL. And **no board built by this pipeline has been fabricated or
powered on yet**, including the example. Passing gates is not working
hardware.

**Setup is push-button. Finishing a board is not.** The install below is
five minutes and then it works. Getting the example board from first
placement to zero clearance violations took about 19 rounds of placement
and routing, each one an edit to `board.toml` and a rebuild, and several
of them needed engineering judgment that no checker was going to supply.
Budget for that. It is the real cost, and nobody who tells you otherwise
has finished a board this way.

---

## 1. Install

```bash
git clone https://github.com/ramalamadingdong/pcb-agent && cd pcb-agent
python3 scripts/doctor.py
```

The doctor names every missing piece and the fix for your OS. Five things
have to line up — KiCad, KiCad's bundled Python, a JVM matching your
Freerouting, the Freerouting jar, and `uv` — and each one fails in a way
that costs you an afternoon if you don't recognise it.

You do not have to satisfy them by hand. The container carries all of
them:

```bash
make setup      # builds the image, fetches the pinned Freerouting jar
make doctor     # reports what the container satisfies
```

`make setup` pins the toolchain: KiCad 10 (digest-pinned base image),
Freerouting 1.9.0, checksum-verified. Once the image exists, every
headless target runs inside it automatically. `./run.sh <cmd>` runs
anything else in there with the repo mounted at `/work`, as your uid and
gid, so nothing lands in your tree owned by root.

Two things the container will not do for you. It has no GUI, so **install
KiCad natively as well** if you want to look at a board — and match the
major version to your boards, because a KiCad 9 `pcbnew` loading a KiCad
10 board returns `None` with no error at all. And `kicad/kicad` images are
linux/amd64, so Apple Silicon runs them under emulation.

## 2. Give the agent its tools

In Claude Code:

```
/plugin marketplace add aklofas/kicad-happy
/plugin install kicad-happy@kicad-happy
```

Eleven KiCad skills by Andrew Klofas — datasheet extraction, EMC, SPICE,
sourcing from DigiKey, Mouser, LCSC and element14, fab prep for JLCPCB and
PCBWay. MIT. This is the install that matters most: it is what lets the
agent read a datasheet's land drawing instead of guessing a footprint.

This repo's own five commands come from `commands/`:

```
/new-board     an idea, interviewed into a cited plan and a netlist.csv
/build         netlist.csv -> schematic -> board -> placement -> zones -> silk
/route         snapshot -> Freerouting -> DRC x5 -> gerbers
/check         validate the fab package against board.toml
/doctor        is this machine able to run any of it
```

## 3. Build the example first

Do not point this at your own design yet. Build the example, which is what
`BOARD_DIR` defaults to:

```bash
make build      # netlist -> schematic -> board -> place -> zones -> silk
make route      # snapshot -> Freerouting -> completion -> DRC x5
make export     # fab package
make check      # the gerber checker, on the real export
```

You are looking for the same gates the example signed off on: **0
unconnected, 0 clearance violations** identical across 5 consecutive DRC
runs, `validate_gerbers` **14 passed / 0 failed**, ERC clean. The 17
residual DRC items are expected — they are form-factor and
courtyard-graze artifacts, each one explained in
[`examples/unoq-power-shield/rev-1-plan.md`](../examples/unoq-power-shield/rev-1-plan.md).

If that reproduces, your toolchain is real. If it doesn't, fix that before
you spend a week on a design — you would be debugging two things at once.

## 4. Your own board

```
/new-board
```

It interviews you: what the board does, whether firmware exists, power,
interfaces, constraints, and what must not go wrong. Then it reads
datasheets and writes two artifacts into your board directory:

- `rev-1-plan.md` — scope, requirements each cited to a document, part
  choices with the reason, capacity math with the arithmetic shown, and
  the gate list that has to pass before anyone orders
- `netlist.csv` — one row per pin, every pin of every IC

**It stops twice for your sign-off**, once after the interview and once
before it writes the netlist. Those stops are the safety story. An
idea-to-board prompt with no stops produces sixty confident rows of
hallucinated pin numbers, and you find out when the boards arrive.

The rule that governs the whole stage: no pin number that didn't come from
a document read in-session and cited. The round-trip diff holds the
schematic to the CSV. Nothing holds the CSV to reality except that rule.

Then write `board.toml` — start from `templates/board.example.toml`, which
is commented section by section, and read
[`your-own-board.md`](your-own-board.md) for what each section drives. One
file configures both the build passes and the checker, in one coordinate
frame with the origin at the board's bottom-left corner.

## 5. The placement loop

```bash
make build BOARD_DIR=path/to/yours
./run.sh kct placement check path/to/yours/your-board.kicad_pcb
```

Placement is a loop, not a step. Fix the **errors** by editing
`[[floorplan.place]]` coordinates and rebuilding; the pass is idempotent,
so re-runs are cheap. The example went 26 → 10 → 6 → warnings-only over
four iterations. That is normal, not failure.

Two things that save rounds here, both learned the expensive way:

- **Place passives by net topology, not by schematic tidiness.** A part
  whose pins exit south, sitting north of its chip, gives the router no
  short path that doesn't graze pads. Rotation is placement too — a part
  in the right spot facing the wrong way is a part in the wrong spot.
- **A bounded copper pour is a wall.** Exported to the DSN it is fixed
  copper, and the router will not cut through it. If the router keeps
  making the same bad choice in the same corner, check whether a pour
  closed the corridor you assumed it would use. Shrink the pour rather
  than fighting the router.

## 6. Route and check

```bash
make route BOARD_DIR=path/to/yours
make export BOARD_DIR=path/to/yours
make check BOARD_DIR=path/to/yours
```

Read the route JSON, not the router's mood. `segments_after_router` must
be well above `segments_before` — a silent no-op is detected and fails,
but look anyway. `unfixed` names the nets completion couldn't finish;
those usually mean a congested corner, so give the parts room in the
floorplan rather than fighting the router. The DRC block shows violation
*kinds* across five runs: stable kinds are real, unstable ones are DRC
nondeterminism.

`make check` runs the level-4 checker on the actual export. Rules you
don't configure report `SKIP`, not `PASS` — investigate SKIPs, don't count
them. A check you haven't written isn't a check that passed.

## 7. Gates before you order

Nothing ships until all of these hold:

- schematic round-trip diff clean (the build fails otherwise)
- ERC clean, DRC ×5 with zero errors and every warning explained
- `make check` green, SKIPs investigated
- every part re-verified in stock **at order time**, not at design time
- the exact ordered files committed byte-for-byte

Anything you catch by hand on the way becomes a line in `board.toml`, so
the checker catches it for you next time. That is the whole point of the
config file.

## What this does not do

It gets you to a package a fab will build and a written reason behind
every choice in it, with respins in hours instead of days because the
fixes are in code.

It does not replace bring-up. Done and clean and fabricated isn't the same
as working — and as of today, nothing built this way has been fabricated
at all.

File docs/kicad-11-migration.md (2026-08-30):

# KiCad 11 and the end of the SWIG bindings

*Findings as of 2026-08-30, against the KiCad developer docs. No code here —
this is the record of what's coming and what our options are.*

## The claim, confirmed

The [PCB Python bindings page](https://dev-docs.kicad.org/en/apis-and-binding/pcbnew/index.html)
of the KiCad developer docs says the SWIG-based `pcbnew` bindings are
**deprecated as of KiCad 9.0**, and, quoting exactly:

> The current plan is to remove the SWIG bindings in KiCad 11.0.

So: present in 9 and 10 (verified by import in both `kicad/kicad:9.0` →
9.0.9 and `kicad/kicad:10.0` → 10.0.5 container images), gone in 11.

## What replaces them, and why it doesn't serve us

The replacement is the [IPC API](https://dev-docs.kicad.org/en/apis-and-binding/ipc-api/index.html):

> The IPC API is an interface that can be used to remotely control a
> **running instance of KiCad**.

It is a client/server protocol — each running KiCad instance acts as the
server, plugins connect as clients. The Pythonic client is
[kicad-python](https://gitlab.com/kicad/code/kicad-python). Two properties
matter for this pipeline:

1. **It operates on a live KiCad process, not on files.** The SWIG bindings
   load a `.kicad_pcb` standalone; the IPC API needs the PCB Editor running.
   The [known headless workaround](https://adamws.github.io/using-the-new-kicad-ipc-api-in-a-ci-environment/)
   is launching the full `pcbnew` GUI under Xvfb with pre-seeded config to
   suppress first-run dialogs — that is, not headless at all, just invisible.
   True headless operation is *planned* upstream, not shipped.
2. **In KiCad 9/10 the IPC API cannot plot or export files at all** — that
   support lands in KiCad 11+.

Our container is deliberately GUI-free (no X11, no VNC — the CLAUDE.md
rule). A headless build container is exactly the environment the IPC API,
as it stands, does not serve.

`kicad-cli` is unaffected by any of this — it is a native binary, and it
keeps doing what it does (ERC, DRC, gerber/drill export, rendering).

## What in this pipeline actually depends on SWIG

Per `scripts/build/CONTRACT.md`, every build pass mutates the board through
`pcbnew` or `kicad-tools`. Roughly:

| Capability | SWIG today | `kicad-cli` | IPC API (11+) | kicad-tools |
| --- | --- | --- | --- | --- |
| Load board standalone | yes | n/a | no — live instance | yes (own parser) |
| Mutate board (place, fanout, repair_pads, silk) | yes | no | yes, via live instance | yes |
| Export DSN for Freerouting | yes (`ExportSpecctraDSN`) | no | unknown | possible to add |
| Import SES | yes | no | unknown | possible to add |
| DRC / ERC | — | yes | 11+ | partial |
| Gerber/drill export | — | yes | 11+ | no |

The gerber checker (`scripts/validate_gerbers.py`) is pure text parsing and
depends on none of this.

## Options

**A. Stay pinned — the container *is* the mitigation.** The Dockerfile pins
`kicad/kicad:10.0` by digest; that image builds boards identically for as
long as Docker exists, regardless of what KiCad 11 removes. The deadline
stops being a cliff and becomes drift management: a host on KiCad 11 will
read KiCad 10 boards fine (formats are backward-readable), and
`scripts/doctor.py` already warns on a host/container major mismatch. Cost:
the build toolchain is frozen; new KiCad features never arrive in the
pipeline.

**B. Migrate mutation passes to `kicad-tools`.** Already a credited
dependency; it parses and writes KiCad files with its own s-expression
engine, no KiCad process at all. This is not "hand-editing board files" —
it is a structured library, the thing the CLAUDE.md rule actually permits.
Pass-by-pass migration is possible since the CONTRACT interface is per-pass.
Cost: DSN export / SES import would need implementing or keeping a pinned
KiCad 10 container around just for those two steps.

**C. IPC-under-Xvfb.** Put X11 back in a container and drive a live KiCad
11. Rejected as the primary path — it contradicts the no-GUI rule, adds a
flaky moving part (poll-until-KiCad-answers), and the workaround exists
precisely because upstream hasn't finished headless mode. Reconsider only
if upstream ships true headless IPC (watch the dev-docs IPC pages and
release notes for it).

**D. Hybrid (likely end state).** `kicad-cli` for everything it covers
(exports, DRC — which 11 keeps growing), `kicad-tools` for mutation, and a
digest-pinned KiCad 10 container held only for `ExportSpecctraDSN` /
`ImportSpecctraSES` until B covers them.

## Recommendation

No action now. Option A holds indefinitely and costs nothing today — the
digest pin and the doctor's drift warning were built for exactly this.
Re-evaluate when KiCad 11 reaches beta: check whether headless IPC shipped,
and whether `kicad-cli` grew DSN/SES round-tripping. The trigger to actually
migrate is the first build pass we *want* that needs a KiCad-11-only
feature — not the removal itself.

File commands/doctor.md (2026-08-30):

---
description: Check that this machine can run the pipeline — KiCad 9, pcbnew, Java, Freerouting, uv. Run this first, and any time a build fails in a way that smells like environment.
---

Run `python3 scripts/doctor.py` and report the result.

If anything is MISSING, walk the user through the fixes it prints, one at a
time, in the order shown. Do not start a build until it exits clean —
a missing `pcbnew` or a backgrounded Freerouting fails silently, and you will
spend the afternoon debugging the board instead of the setup.

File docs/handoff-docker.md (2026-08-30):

# Handoff: containerize the pcb-agent pipeline

Paste this into Claude Code from the root of the `pcb-agent` repo.

---

You're working in the `pcb-agent` repo. Read `README.md`, `CLAUDE.md`, and
`scripts/build/CONTRACT.md` first — they describe a KiCad build pipeline where
`netlist.csv` is the source of truth and the KiCad files are build outputs.

The goal: someone should be able to run the headless parts of this pipeline
(`build`, `route`, `check`) without installing KiCad, Java, and Freerouting by
hand. They will still install KiCad natively to *look* at the board — that
part isn't containerizable and shouldn't be.

Work through these in order. Verify each step before moving on; don't assume a
result you haven't seen.

## 1. Answer the open question

Does the official KiCad image ship the SWIG `pcbnew` Python module, or only
the `kicad-cli` binary?

```bash
docker run --rm kicad/kicad:9.0 python3 -c "import pcbnew; print(pcbnew.GetBuildVersion())"
```

If that fails, try locating the module and setting `PYTHONPATH` before
concluding it's absent — at least one person running Python bindings in a
container had to point `PYTHONPATH` at KiCad's bundled modules explicitly.

Report what you find. It decides step 2.

## 2. Write the Dockerfile

- **If `pcbnew` imports from `kicad/kicad:9.0`** — base on it. Smaller, and
  version-pinned by the KiCad project.
- **If it doesn't** — base on `debian:bookworm` and install KiCad 9 from apt,
  where the bindings land in system-wide dist-packages and any Python 3 on the
  system can import them.

Either way, add:

- A JRE (21 unless Freerouting's pinned release needs otherwise)
- The Freerouting jar at a fixed path, **pinned to a specific release**, with
  its checksum verified at build time
- `uv`
- A non-root user whose UID/GID can be set by build arg, so files written to
  the mounted volume aren't owned by root

Do **not** put a GUI, X11, or VNC in it. The container builds; the human
reviews on the host.

## 3. Wire it up

- `docker-compose.yml` (or a `run.sh`) mounting the project directory as a
  volume, working dir inside it
- `make setup` — builds the image; also fetches the pinned Freerouting jar to
  `tools/` for people running natively, checksum-verified
- `make build` / `make route` / `make check` — run inside the container when
  it exists, fall back to local otherwise
- Update `scripts/doctor.py`: if the image is present, report the container as
  satisfying kicad/java/freerouting, and **compare the host's `kicad-cli
  --version` against the container's**, warning on a major-version mismatch.
  Host and container drifting apart is the failure mode this design creates.

## 4. Prove it

Don't declare it done on a successful `docker build`. Show me:

- `python3 scripts/doctor.py` inside the container, exiting clean
- `import pcbnew` working as the non-root user
- Freerouting running a real DSN to completion, foreground, `-mt 1`
- `scripts/validate_gerbers.py` passing on a known fab package
- A file written from inside the container, owned by my host user, not root

## 5. Then check something for me

The SWIG `pcbnew` bindings are reportedly present in KiCad 9 and 10 but
removed in KiCad 11, replaced by an IPC API that needs a running KiCad
instance rather than operating on files directly. Confirm whether that's
accurate against current KiCad developer docs.

If it is, this whole pipeline has a deadline, and a headless container is
exactly the environment the replacement API doesn't serve. Write what you find
to `docs/kicad-11-migration.md` — findings and options, no code yet.

## Rules

Same as `CLAUDE.md`. In particular: don't trust a tool's report of its own
success, pin every version you introduce, and if something doesn't work say
so plainly rather than working around it quietly.

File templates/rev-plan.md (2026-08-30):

# rev-<N> plan

**Status:** draft | in build | ordered
**Date:**

## Scope
What this revision is for, in one paragraph.

## Defect it fixes
If this is a respin: what was wrong with the last one, how it was found, and
the change that addresses it. If a checker missed it, note the rule added to
`board.toml` so it can't be missed again.

## Requirements
From firmware where it exists, every line citing file and line number.
Mark `ASSUMED` where there is no firmware yet.

| # | Requirement | Source |
| - | --- | --- |

## Parts
| RefDes | Part | Price | Stock | Lead | Why | Datasheet |
| --- | ---- | ----- | ----- | ---- | --- | --- |

Rejected alternatives and why:

## Capacity math
- Data rate vs storage:
- Current vs trace width (IPC-2221, __ oz copper):
- Dissipation vs package:
- Battery capacity vs average draw:

Numbers that changed from the last revision, and why:

## Gates — all must pass before ordering
- [ ] Schematic round-trip diff clean against `netlist.csv`
- [ ] ERC clean
- [ ] DRC run 5+ times, comparing which violations appear
- [ ] `validate_gerbers` PASS
- [ ] Every part in stock, re-verified at order time
- [ ] Ordered files committed byte-for-byte
- [ ] (board-specific gates here)

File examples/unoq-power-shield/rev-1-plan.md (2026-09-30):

# rev-1 plan — UNO Q power & I/O demo shield

**Status:** draft — awaiting sign-off before netlist
**Date:** 2026-08-30

## Scope

A power and I/O demo shield for the Arduino UNO Q, built as this repo's
known-good example board. Screw-terminal VIN (7–24 V) feeds the UNO Q's own
VIN pin and a local 5 V buck; an INA226 reports the whole stack's current
and voltage over I²C; four BSS138 channels level-shift between the UNO Q's
3.3 V headers and 5 V peripherals; Qwiic passthrough; RGB status LED. Cheap
and boring on purpose — its job is to exercise every check in `board.toml`
for a reason a first-time user can see, not to be clever.

## Defect it fixes

First revision — no respin history. One rule here exists because of a defect
on another board: rev D2 of a previous project shipped fiducials as bare
copper dots with no X2 `AperFunction` tag, so gerber-level checking could
not see them. The fiducials gate below requires the tag, verified by
`validate_gerbers` reporting them found.

## Coordinate frame

All coordinates below are the **UNO Q fab frame**: portrait, origin at the
bottom-left of the top view, X across the 53.34 mm width (JANALOG west,
JDIGITAL east), Y along the 68.58 mm length, antenna/USB-C edge at
Y = 68.58. The shield uses the same frame — stacked, shield (x, y) sits
directly over UNO Q (x, y).

## Requirements

Sources: `docs/datasheets/ABX00162-ABX00173-datasheet.pdf` (the UNO Q
datasheet, page numbers as printed), `ABX00162-full-pinout.pdf`,
`ABX00162-schematics.pdf` (sheet numbers), and the fab data inside
`ABX00162-cad-files.zip` (Allegro gerbers + NC drill, the exact files
Arduino manufactures from). Firmware does not exist yet; derived lines are
marked `ASSUMED`.

| # | Requirement | Source |
| - | --- | --- |
| R1 | Outline 68.58 × 53.34 mm, UNO form factor, chamfered corners at the Y=0 end | datasheet §12 p.35 |
| R2 | 4 mounting holes Ø3.2 mm NPTH at (50.80, 53.34), (35.56, 2.54), (7.62, 2.54), (2.54, 54.61) — fixed by the UNO pattern, not ours to choose | drill file `48DMVQAD1_SGB-20250729a4-1-8.drl` T08 block (3.200 mm NON_PLATED ×4); datasheet §12 "4x R1.6" |
| R3 | Header pins Ø1.05 PTH, 2.54 pitch, four strips: JANALOG power 8-pin X=2.54, Y 40.64→22.86 (BOOT, IOREF, RESET, +3V3, +5V, GND, GND, VIN); JANALOG analog 6-pin X=2.54, Y 17.78→5.08 (A0→A5); JDIGITAL 10-pin X=50.80, Y 49.78→26.92 (D21, D20, AREF, GND, D13→D8); JDIGITAL 8-pin X=50.80, Y 22.86→5.08 (D7→D0) | same drill file T04 block (starts + R-code repeats, 32 pins total); pin order from full-pinout p.1 |
| R4 | VIN accepts 7–24 V; the UNO Q's own VIN pin (JANALOG pin 8) takes the same range and feeds the Q's internal buck | datasheet §3.1 p.10, §3.2 p.11 |
| R5 | All shield-facing logic is 3.3 V. A0/A1 not 5 V-tolerant in any mode; ~D3 (PB0) is TT-type, 3.6 V max even in digital mode; other digital pins 5 V-tolerant as inputs only | datasheet §9 p.21, §9.6 note pp.28–29; full-pinout p.1 warning |
| R6 | Shield I²C = I2C2 on D20 (SDA, PB11) / D21 (SCL, PB10). The UNO Q already has 2.2 kΩ pull-ups to 3.3 V on these lines — the shield adds none | datasheet §9.6 p.28; schematics sheet 20 ("IO"), R2642/R2643 2.2K to PWR_3P3V on MCU_I2C2_*_CONN |
| R7 | Wi-Fi PCB antenna occupies X 0.76–22.1, Y 63.9–68.07 (top-left corner, meandered trace). Shield keepout over it, all copper layers, pads included: **X 0–26, Y 61–68.58** | `top.art` gerber copper extraction + 600 DPI render; module WCBN3536A location full-pinout p.1; datasheet §2.2.2 p.7 "shared PCB antenna" |
| R8 | The Q's VIN input already carries reverse-polarity protection (verified at −24 V) and a 24 V TVS — the shield does not duplicate the TVS, but must protect its *own* electronics from reversal | datasheet §3.1 p.10; schematics sheet 20, D26201 PJGBLC24C on DC_IN |
| R9 | +5V header pin is USB VBUS passthrough (power only); IOREF mirrors 3.3 V, output-only, never back-fed. The shield passes both through untouched | datasheet §9.7 p.29 |
| R10 | Max component height on the UNO Q top side is 8.5 mm (the headers themselves); USB-C region ~3 mm. Shield bottom side: no parts (SMT top-only), so stacking clears | datasheet §12 p.35 side view (`ASSUMED`: 8.5 mm = header height, the drawing does not label which part) |
| R11 | Shield 5 V rail budget 1.5 A continuous / 2 A peak for user loads | `ASSUMED` — design choice |
| R12 | INA226 at I²C address 0x40 (A0=A1=GND), measuring total stack VIN current + bus voltage; ALERT open-drain to ~D3 with 10 k pull-up to 3.3 V (D3 is safe for it precisely because ALERT never exceeds 3.3 V — the pin you must not put 5 V on) | INA226 ds pin table + address Table 6-2; `ASSUMED` role |
| R13 | 4 shifted channels on D2, D4, D7, D8 (plain GPIOs; D4 doubles as FDCAN1_TX — CAN unusable while shield IO4 in use, documented) | full-pinout p.1; `ASSUMED` pin choice |
| R14 | RGB LED on ~D9/~D10/~D11 (TIM4_CH3/TIM4_CH4/TIM1_CH3N PWM), active-low, common-anode to shield 5 V | full-pinout p.1; LED polarity XL-1615 ds p.8; `ASSUMED` pin choice |
| R15 | JLCPCB SMT assembly, top side only; screw terminals THT-assembled; header positions DNP (user fits stacking headers — JLC cannot source them) | constraint from Phase 0 |
| R16 | 4-layer: L2 solid GND plane, L3 power plane — both routing-banned | design choice for the `planes` rule |

## Parts

All availability and Basic/Extended status checked against JLCPCB's own
component endpoint on 2026-08-30 (`componentLibraryType`: base/expand).
Datasheets in `docs/datasheets/`.

| RefDes | Part | LCSC | Lib | Price | Stock | Why | Datasheet |
| --- | ---- | ---- | --- | ----- | ----- | --- | --- |
| U1 | TPS54331DDAR buck, 3.5–28 V in, 3 A, SO-8 PowerPAD | C90761 | ext | $0.52 | 45k | 24 V max input needs ≥28 V part; **exposed pad is required** (it is what the thermal-via rule checks); TI ds has a full design procedure + layout guide | TPS54331DDAR.pdf (§ "3.5 to 28-V input", PowerPAD) |
| U2 | INA226AIDGSR current/power monitor, VSSOP-10 | C49851 | ext | $0.86 | 81k | senses 0–36 V common mode — 12 V margin over 24 V VIN; ±81.92 mV shunt range; 16 addresses | INA226AIDGSR.pdf (§ "0V to 36V", shunt range table) |
| Q1–Q4 | BSS138LT1G N-FET, SOT-23 | C82045 | ext | $0.044 | 708k | classic bidirectional shifter; V_GS(th) 0.5–1.5 V works from a 3.3 V gate; no edge-rate one-shots to misfire on breadboard wiring | BSS138LT1G.pdf (V_GS(th) 0.5–1.5 V) |
| Q5 | AO4407A P-FET −30 V −12 A, SOIC-8 | C2841482 | ext | $0.13 | 159k | reverse-polarity protection at the terminal; R_DS(on) <13 mΩ @ −10 V → 0.2 W at 4 A | AO4407A.pdf (V_DS −30 V, V_GS ±25 V) |
| D1 | SS34 Schottky 40 V 3 A, SMA | C8678 | **base** | ~$0.02 | 4.9M | TPS54331 is non-synchronous — external catch diode; 40 V > 24 V in, V_F 0.55 V @ 3 A | SS34.pdf |
| D2 | BZT52C12 zener 12 V, SOD-123 | C173429 | ext | ~$0.01 | 358k | clamps Q5's V_GS: at 24 V input the gate would sit 1 V from the ±25 V abs max — no margin without it | BZT52C12.pdf; AO4407A.pdf V_GS spec |
| D3 | XL-1615RGBC-RF RGB LED, 1.6×1.5, common anode | C965840 | ext | $0.02 | 571k | pin 2 = common anode (drawing p.8 — the drawing wins), 20 mA/die max; driven at ~6–9 mA | XL-1615RGBC-RF.pdf p.3, p.8 |
| L1 | SWPA6045S100MT 10 µH, 6045 | C79272 | ext | ~$0.10 | 13k | I_sat 3.20 A > 1.9 A worst-case peak; I_rms 2.45 A > 1.5 A budget; DCR 62 mΩ | SWPA-series-Sunlord.pdf (6045S100MT row) |
| R_sh | HoYLR2512-3W-10mR-1% shunt | C5375464 | ext | $0.055 | 155k | 40 mV @ 4 A — half of INA226 full scale; 0.16 W of a 3 W rating | HoYLR2512-3W-10mR.pdf |
| J1, J2 | KF301-5.0-2P screw terminal (VIN in; 5 V out) | C474881 | ext | $0.10 | 91k | THT, 5.0 mm pitch, the boring reliable choice | KF301-5.0-2P.pdf |
| J3, J4 | SM04B-SRSS-TB JST-SH 4-pin (Qwiic ×2, daisy-chain) | C160404 | ext | $0.21 | 74k | genuine JST; Qwiic passthrough on I2C2 + 3V3 + GND | SM04B-SRSS-TB.pdf |
| — | 0603 passives (10 k pulls ×~10, LED resistors ×3, buck R/C set), fiducials | — | base | — | — | exact base-library codes picked at netlist time with values from the TPS54331 design procedure | — |
| — | headers: 4 strips per R3, DNP | — | — | — | — | plated holes only; user fits an Arduino stacking-header kit | — |

Extended-part lines: 10 (~$3 loading fee each at JLC — noted in the README
cost estimate; every remaining line is Basic or DNP).

**Rejected:**

- *MP1584EN* (C15051) — also SOIC-8-EP and workable, but $2.92 vs $0.52,
  thinner stock, and a far weaker datasheet than TI's for teaching.
- *TPS54202* (C191884, $0.24) — cheaper, but SOT-23-6 with **no exposed
  pad**: it would delete the very thermal-via lesson the board exists for.
- *INA219* — 26 V absolute max bus voltage against a 24 V nominal input; an
  unloaded 24 V wall supply drifts higher than that. INA226's 36 V removes
  the class of failure.
- *TXS0104E* — one part instead of twelve, but its edge-rate accelerators
  glitch on capacitive/breadboard loads, which is exactly how a first-time
  user will wire it. BSS138 pairs are slow and unkillable.
- *WS2812-class addressable RGB* — would have showcased the level shifter
  (its data threshold genuinely needs 5 V logic), but WS2812 timing through
  a BSS138+10k shifter is marginal — a first-build trap, not a demo.
- *AO3401A* (C15127, Basic) — the only Basic P-FET candidate, but SOT-23 at
  ~55 mΩ would dissipate ~0.9 W at 4 A. Not survivable; the Extended
  AO4407A stays.

## Architecture

```
J1 VIN(7-24V) ── Q5 (P-FET, reverse) ── Rsh 10 mΩ ──┬── UNO Q VIN pin (JANALOG 8)
                 gate: 10k to GND,                   └── U1 TPS54331 ── L1 ── 5V rail
                 BZT52C12 clamps VGS      INA226 across Rsh,                 │
                                          VBUS sense downstream,      ┌──────┴──────┐
                                          I²C2 (D20/D21), addr 0x40,  J2 5V out   HV side of Q1-Q4
                                          ALERT → ~D3 (10k to 3V3)                 (LV side → D2,D4,D7,D8;
                                                                                    LV pull-ups to +3V3 pin)
RGB: 5V ── XL-1615 anode; R,G,B cathodes ── 330R ── ~D9/~D10/~D11 (active-low)
Qwiic ×2: I2C2 + 3V3 + GND (pull-ups are the UNO Q's own 2.2k — none here)
All 32 header pins pass through; +5V-USB and IOREF untouched (R9).
```

The INA226 sits **upstream of the split**, so it reports the whole stack's
consumption — UNO Q included — which is the demo: the shield tells you what
the system draws.

Power-source matrix (for the README): USB-C only → Q runs, shield logic
dead (by design, 5 V rail needs VIN); VIN only → everything runs, Q powered
through its VIN pin; both → Q diode-ORs internally (datasheet §3.1), no
contention because the shield never drives the 5 V or 3V3 header pins.

## Capacity math

- **Total VIN current, worst case (7 V input):** UNO Q ≤ 15 W (assumed from
  its USB-C 5 V/3 A contract, §3.1) ÷ 0.9 buck η ÷ 7 V = 2.4 A, plus shield
  5 V × 1.5 A ÷ 0.9 ÷ 7 V = 1.2 A → **3.6 A; design to 4 A**.
- **IPC-2221 trace width, 1 oz external, ΔT = 10 °C:**
  A = (I / (0.048 · 10^0.44))^(1/0.725) mil². 4 A → 110 mil² → **2.0 mm**;
  1.5 A → 28 mil² → 0.53 mm → 0.8 mm floor. VIN routed as ≥2.0 mm /
  pours; `board.toml` enforces the 0.8 mm floor on every power net
  (a floor for the checker, not the design width).
- **Shunt:** 40 mV @ 4 A = 49 % of INA226 ±81.92 mV range; 0.16 W of 3 W;
  LSB 2.5 µV → 0.25 mA resolution.
- **Buck ripple/peaks (worst at 24 V in):** ΔI = 5 V·(1−5/24)/(10 µH·570 kHz)
  = 0.69 A p-p → peak 1.5 + 0.35 = **1.9 A < 3.2 A I_sat**; I_rms ≤ 1.5 A
  < 2.45 A rating.
- **Buck thermals:** ~0.6–0.8 W loss at 1.5 A/24 V (conduction 80 mΩ HS +
  switching, per ds efficiency section); PowerPAD with stitched vias
  θJA ≈ 42 °C/W → ΔT ≈ 25–35 °C. Fine to 60 °C ambient (the Q's own
  operating ceiling, §3.2). Thermal via count per TI layout guideline —
  gate below.
- **Q5:** 13 mΩ @ V_GS −10 V → 0.21 W at 4 A in SOIC-8. V_GS clamped ~12 V
  by D2 (abs max ±25 V — unclamped at 24 V input leaves 1 V margin: not
  acceptable).
- **Level shifter:** 10 k pulls × ~30 pF ≈ 0.3 µs rise → good to ~300 kHz.
  Not for NeoPixels or fast SPI; the README says so.
- **RGB:** (5 − V_F − V_OL)/330 Ω ≈ 6–9 mA per die vs 20 mA max (exact
  values from the ds electrical table at netlist time).

## Board rules this design exercises (→ board.toml)

| Rule | Physical reason here |
| --- | --- |
| thermal vias | U1's PowerPAD is the only path that keeps the buck ≤35 °C over ambient |
| power width ≥0.3 mm + F.Cu pours | VIN carries up to 4 A, but the 0.8 mm the IPC-2221 math implies cannot enter a 0.3 mm pad (the rev-D lesson). Surface power tracks are short hops at 0.3; the current path is the In2 plane plus the bounded F.Cu VIN/VIN_RAW/VIN_PROT pours, whose cross-section satisfies the math. Rationale in `board.toml [nets.power]` |
| mounting holes 4×3.2 | fixed by the UNO drill file, coordinates in R2 |
| planes In1/In2 | solid GND under the switcher; power plane |
| keepout X 0–26, Y 61–68.58 | the UNO Q's Wi-Fi antenna is directly below — copper there detunes the radio |
| fiducials 3, X2-tagged | JLC assembly; and the rev D2 lesson: untagged fiducials are invisible to the checker |

## Gates — all must pass before ordering

Signed off 2026-08-30 except the two that can only close at order time.

- [x] Schematic round-trip diff clean against `netlist.csv`
- [x] ERC clean (0 violations)
- [x] DRC run 5+ times, comparing which violations appear — 5 identical
      runs: 17 violation(s) in 3 kind(s), **0 unconnected**, no unstable
      kinds. Every residual is in the ledger below; **0 clearance
      violations**.
- [x] `validate_gerbers` PASS with this board's `board.toml` — 14 passed,
      0 failed (2 SKIPs: unmatched mask/paste files, no RF budget)
- [x] `check_placement` PASS — 5 passed, 0 failed. Every edge-mating
      connector (J1, J2 screw terminals; J3, J4 Qwiic) reaches its edge and
      has a clear mating corridor, with two acknowledged screw-head grazes
      (see below); antenna keepout clear of tracks, vias, pads and pour in
      the board file as well as the gerbers
- [x] Antenna keepout verified **in the gerbers** (not the KiCad file) —
      `keepouts/unoq_wifi_antenna` clear on all 4 layers
- [x] Thermal vias under U1 ≥ the TI layout guideline count — 4/4 in the
      PowerPAD region
- [x] Fiducials found by the checker (proves X2 AperFunction tags) — 3
      found, 10.13 mm off-axis
- [x] Shield drill pattern matches R2/R3 coordinates exactly — checker
      `drill/mounting-holes` 4×3.2 mm at the UNO drill positions,
      `frame/origin` within 0.050 mm
- [x] Every part in stock (verified against JLC 2026-08-30, all 24 lines)
      — **re-verify at order time**
- [ ] Ordered files committed byte-for-byte (open until the order is
      actually placed)
- [x] README carries the CC BY-SA 4.0 attribution for Arduino's documents

### Change after sign-off — 2026-09-02, silkscreen only

Four `[[silk.text]]` markings were printing on pads, and J5's named the
wrong rail (`3.3V LOGIC` on the 5 V side of the level shifters). Corrected
in `board.toml`; `silk_finish` gained the pad-collision check that should
have caught it — see that pass's docstring.

Copper was NOT re-routed. Only `silk_finish` and the export were re-run,
and the gerbers prove it: F.Cu, In1.Cu, In2.Cu, B.Cu, Edge.Cuts, both mask
and both paste layers, and both drill files are **byte-identical** to the
signed-off package (modulo the generation timestamp). `F_Silkscreen` is
the only file that changed. Gates re-run on the new package: checker 14/0,
DRC ×5 → 17 violations / 3 kinds / **0 unconnected**, unchanged.

## Residual DRC ledger — every remaining violation, explained

17 items in 3 kinds, identical across 5 consecutive DRC runs. None is a
clearance or connectivity defect; each is either the UNO form factor or a
conservative-courtyard graze with real body-to-body space.

| Kind | Count | Explanation |
| --- | --- | --- |
| `copper_edge_clearance` | 4 | All four are J4's pads (Qwiic, JST SM04B side-entry): the connector mounts at the board edge by design, so its pads sit inside the 0.5 mm edge rule. Land pattern per the SM04B datasheet. |
| `pth_inside_courtyard` | 1 | J13 pin 10 inside mounting hole H1's courtyard. Both positions are Arduino's — fixed by the UNO Q drill data — and every real UNO shield carries this same adjacency. |
| `courtyards_overlap` | 12 | 3 are the same UNO form-factor fixture (H1/J13, H2/J4, H3/J1). The other 9 are courtyard-to-courtyard grazes in the deliberately tight power stage (L1 vs C6/C7/C8/C9/D1, D1 vs C2/C3, Q5/D2, R1/R16): bodies clear, conservative courtyards touch. The placement check reports the same set as 13 warnings, 0 errors. |

### Connector-accessibility findings — 2026-09-06

`check_placement.py` was added to the pipeline and run against this board.
It independently rediscovered **two of the three UNO-fixture adjacencies**
already in the ledger above, and said something about them the DRC did not:

| Finding | What DRC called it | What the corridor check adds |
| --- | --- | --- |
| H3 ∩ J1, 3.0 mm² | `courtyards_overlap` | H3's **screw head** (6 mm, not the 3.2 mm hole) reaches ~1.9 mm into the left pole's wire entry on a KF301 screw terminal — an assembly note, not a graze. Use a countersunk M3. |
| H2 ∩ J4, 0.5 mm² | `courtyards_overlap` | Corner graze of the Qwiic cable exit; the ribbon leaves the other way. |

Both are Arduino's fixed hole positions against the only free edge, so they
are unfixable at this outline. Both are declared `accept_blockers` in
`board.toml` with the reason inline — still measured, still printed as
`accepted:`, downgraded rather than hidden. The third fixture adjacency
(H1/J13) involves a stacking header, which mates from above and is
deliberately not modelled by this check.

### Findings from the new gates — 2026-09-30 (fixed, see the rebuild below)

Three gates were added (a gated DRC ledger, a derived connector orientation,
and a pad-angle check). Two of them fail this board as committed. Both
defects were in the package the earlier gates passed.

| Finding | Evidence | What the earlier gates said |
| --- | --- | --- |
| **J4 is rotated 180°.** Its signal leads face the bottom edge and the Qwiic socket opens *into* the board. | SM04B-SRSS-TB.pdf p.3: side-entry leads exit the rear of the 4.25 mm body, so the opening is on the reinforcement-tab side (+y in the footprint). J4 at 180° puts +y at board top. J3, the same footprint at 270°, is correct. `img/board-assembled.png` shows J3's housing open toward the left edge, and J4's pins at the edge. | The ledger read the 4× `copper_edge_clearance` on J4's pads as "at the board edge by design". It was the symptom of this rotation. `check_placement` passed because it trusted the declared face. |
| **16 pads on R3–R7, C1, C6, C7 lie along the part axis.** Each is at 0° on a footprint rotated 90/270. On C1 (1206) the 1.8 mm pad length runs along the part instead of across it. | `fix_pad_angles.py --check` on both `pre_route.kicad_pcb` and the routed board. `fix_pad_angles` corrects all 16 on a scratch copy. | DRC reports no error for a pad at the wrong angle that still clears its neighbours. |

Fix, in the pipeline and not in the board file:
- **J4:** `[[floorplan.place]]` J4 rotation 180 → 0. Re-tune its y, because at
  0° the body overhangs the outline by 0.07 mm.
- **Pads:** a rebuild in the pinned container (2026-09-30) comes out
  correct, and the stripping pass was not reproduced. `make build` runs
  `fix_pad_angles` a second time as insurance, and `make check` gates on it.

Then rebuild, re-route, re-export and re-check. Drop the
`copper_edge_clearance` J4 entry from `[[drc.accept]]`: with J4 turned
around, its reinforcement tabs sit at the edge, not its signal pads. If DRC
still flags the tabs, that needs its own explanation. Until then this board
is not signed off.

**A third finding came from the first end-to-end container run:
`finish_routes` laid redundant copper.** Its `clusters_for` never joined a
segment's two ends, so every routed net with a segment longer than its width
looked broken. pcbnew counted **0** missing links before the pass. The pass
still worked 26 nets, laid 98 links, and reported 14 nets as NO PATH FOUND.
`cleanup_pass` then deleted 92 exact duplicates. The committed board carries
the rest. The bug is fixed, and on a rebuild of this board:

| | before the fix | after |
| --- | --- | --- |
| segments (final) | 492 | 294 |
| vias | 123 | 54 |
| track length | 1536 mm | 913 mm |
| DRC ×5 | 17 errors (all ledgered), 0 unconnected | identical |
| `finish_routes` unfixed | 14 nets | none |

`route.py` now records pcbnew's count just before the pass
(`unrouted_before_completion`), and warns if the pass works nets that pcbnew
calls connected.

The residual-DRC ledger above now lives in `board.toml` as `[[drc.accept]]`,
with the exact refs, and is enforced by `drc_sample.py`. The 13 DRC warnings
(silk overlaps; `via_dangling` on VIN_PROT and VIN_RAW) are reported and not
gated. The two dangling vias deserve a look on the rebuild.

### Rebuild — 2026-09-30

`[[floorplan.place]]` J4 was changed to rotation 180 → 0 and y 3.2 → 3.4.
At 0° the MP tabs face the edge, and 3.4 keeps them 0.625 mm clear of the
0.5 mm rule. The J4 `copper_edge_clearance` ledger entry was deleted. The
board was then rebuilt from `netlist.csv` in the pinned container (KiCad
10.0.5, Freerouting 1.9.0) with `make build route export check`. Results:

| Gate | Result |
| --- | --- |
| Schematic round-trip | 159/159 nodes |
| ERC | 0 errors |
| Pad angles | all at footprint rotation + library angle |
| DRC ×5 | 13 errors, identical every run, all in `[[drc.accept]]`; 0 unconnected; no stale entries. J4's 4× `copper_edge_clearance` is gone |
| `check_placement` | 11 passed, 0 failed. J4: opening +y → bottom, 0.12 mm to the edge |
| `validate_gerbers` | 15 passed, 0 failed, 2 SKIP (mask/paste layers unmodelled; no RF budget) |
| IPC-D-356 vs `netlist.csv` | 159/159 pins, none extra |
| Route | 272 segments from the router, 29 plane links (GND/5V) left and closed by pour vias; `finish_routes` re-routed only 3V3_UNO, a segment it stripped for grazing a GND via by 0.158 mm |
| Score | 60 vias, 881.5 mm of track |

`drc_report.json`, `erc_report.json` and `img/*.png` were regenerated from
the rebuilt board, the PNGs with native KiCad because the container has no
3D models.

The floorplan anchors all 49 parts, so nothing is free to move and the
board is exactly the hand floorplan. The optimiser used to run anyway and
end every round with "infeasible placement", because the ledgered courtyard
grazes count as overlap. `place.py` now sees 0 free parts, skips it, and
runs only the pad repair and the conflict score (13 conflicts, the ledgered
grazes). A scratch rebuild with that change passes every gate. The
consequence stands: this example does not exercise the optimiser.

Still to do at order time (the gate list above): re-verify every part in
stock, and commit the exact package you upload. `fab/` is gitignored, so
the zip has to be added deliberately.

## Open items (blocking netlist, not blocking sign-off)

- TPS54331 compensation/feedback values from the ds design procedure,
  mapped to Basic-library E-series codes
- Exact base-library codes for all passives
- Thermal-via count + PowerPAD land pattern from TPS54331 ds §layout
- INA226 averaging/conversion config is firmware's job — no hardware impact

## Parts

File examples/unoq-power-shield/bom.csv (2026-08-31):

Comment | Designator | Footprint | LCSC Part #
TPS54331DDAR | U1 | SOIC-8-EP | C90761
INA226AIDGSR | U2 | MSOP-10 | C49851
BSS138LT1G | Q1 Q2 Q3 Q4 | SOT-23 | C82045
AO4407A | Q5 | SOIC-8 | C2841482
SS34 | D1 | SMA | C8678
BZT52C12 | D2 | SOD-123 | C173429
XL-1615RGBC-RF | D3 | SMD1615 | C965840
SWPA6045S100MT | L1 | SMD6045 | C79272
KF301-5.0-2P | J1 J2 | P5.0-2P | C474881
SM04B-SRSS-TB | J3 J4 | JST-SH-4P | C160404
10mR 3W 1% | R1 | R2512 | C5375464
10K 0603 1% | R2 R8 R9 R10 R11 R12 R13 R14 R15 R16 | R0603 | C25804
120K 0603 1% | R3 | R0603 | C25808
33K 0603 1% | R4 | R0603 | C4216
27K 0603 1% | R5 | R0603 | C22967
5.1K 0603 1% | R6 | R0603 | C23186
24K 0603 1% | R7 | R0603 | C23352
330R 0603 1% | R17 R18 R19 | R0603 | C23138
4.7uF 50V X7R 1206 | C1 C2 | C1206 | C51205
100nF 50V X7R 0603 | C3 C4 C10 | C0603 | C14663
10nF 50V 0603 | C5 | C0603 | C57112
1nF 50V 0603 | C6 | C0603 | C1588
100pF 50V 0603 | C7 | C0603 | C14858
22uF 25V X5R 1206 | C8 C9 | C1206 | C12891

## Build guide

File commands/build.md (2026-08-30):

---
description: Build the board from netlist.csv — schematic, PCB, placement, zones, fanout, silk. Run after any netlist change.
---

Run `make build`.

Before you start, confirm `scripts/doctor.py` exits clean. A missing `pcbnew`
or the wrong KiCad fails in ways that look like design problems.

Watch for three things and stop if you see any of them:

- **The round-trip check failing.** Every net in `netlist.csv` must come back
  out of the generated schematic. This is the check that catches a label a
  fraction of a millimetre off a pin — a schematic that looks perfect and
  carries no net.
- **An empty net table** after any board write. `grep -cE '^\s*\(net [0-9]+ '`
  must be non-zero. If it's zero the router will report "nets to route: 0"
  and do nothing, with no error anywhere.
- **Collapsed pads** after the optimiser. If both pads of a two-pad passive
  sit at the same coordinate, `repair_pads` didn't run or didn't restore
  rotation.

When it finishes, snapshot before routing. Do not route in this script.

If something is wrong with the board, fix `netlist.csv` or a pass and rebuild.
Never edit the board file. The next rebuild wipes it.

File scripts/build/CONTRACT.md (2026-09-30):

# The pass contract

Every script in this directory is a **pass**: one step of
`netlist.csv -> build -> board -> snapshot -> route -> gerbers -> check`.
They are run by the Makefile and by `route.py` / `place.py` as subprocesses,
never imported for their side effects. This file is what every pass
promises, so that a new one can be written against it and an old one can be
replaced (a SWIG pass by a `kicad-cli` or IPC pass, say) without the rest of
the pipeline noticing.

## Arguments

Built by `_lib.pass_parser`:

| flag | meaning |
| --- | --- |
| `--board PATH` | the `.kicad_pcb` the pass reads and (usually) rewrites in place |
| `--schematic PATH` | instead of, or as well as, `--board` for schematic passes |
| `--netlist PATH` | `netlist.csv`, the source of truth. Accepted by every pass for uniformity, even those that ignore it |
| `--config PATH` | `board.toml`. Every tunable lives here, never in a pass's source |

A pass may add its own flags (`place.py --rounds`, `route.py --snapshot`).
It must not require a flag the Makefile doesn't pass.

## Output

- **stdout carries exactly one line: a JSON object** from `_lib.emit(name, ...)`,
  with `"pass": <name>` and whatever the pass changed or measured. The
  agent reads this line to confirm what actually happened instead of assuming.
  Callers (`route.py::run_pass`) take the *last* line that parses as JSON.
- **Everything else goes to stderr.** That includes progress, warnings, and
  PASS/FAIL tables.
- A checker that fails still emits its JSON line first, then exits non-zero
  (`check_placement.py`, `drc_sample.py`, `erc_check.py`). The report is the
  evidence, and a failure without evidence is useless.

## Exit codes

| code | meaning |
| --- | --- |
| 0 | the pass did its job (a checker: nothing unaccepted failed) |
| 1 | failure. The board may be half-written; rebuild from an earlier stage |
| other | pass-specific and documented in the pass. `finish_routes.py` exits 1 for "nets remain unfinished", which `route.py` allows and reports |

`_lib.fail(msg)` prints to stderr and exits 1. Use it for anything the user has
to fix. Never swallow an error and exit 0.

## Idempotency

**Running a pass twice must give the same board as running it once.** You
will re-run a stage when you aren't sure it ran; an appending pass turns that
into junk copper.

- **Strip, then rebuild.** A pass that adds objects (fiducials, keepouts,
  stitching vias, silk) first removes what it previously added, identified by
  a name or group it owns, then adds.
- **Assign absolutely, never relatively.** `floorplan.py` writes positions,
  never offsets, and unlocks every ref that isn't in its table.
- **No randomness in written files.** `generate_schematic.py` seeds uuid4
  (`deterministic_uuids`) so an unchanged netlist gives a byte-identical
  schematic.
- **Stochastic passes are restartable, not repeatable.** `place.py` (CMA-ES)
  and `route.py` (Freerouting) can't be byte-identical. Instead they start
  from a fixed input (the board as it stands, or `pre_route.kicad_pcb`), never
  append, and keep the best measured result.

## Writes

- Passes rewrite `--board` in place. Text writes go through
  `_lib.write_text_atomic` (a sibling temp file, then `os.replace`), so a
  crash mid-save leaves the previous file, never a truncated one.
  `pcbnew.SaveBoard` writes are **not** atomic, and that is deliberate:
  saving to a temp name also writes `<temp>.kicad_pro` / `.kicad_prl` and
  stamps the temp name into the project's `meta.filename` (measured on KiCad
  10.0.5). A crashed SWIG pass means rebuilding from the previous stage.
- **Assert the net table after every board write** (`_lib.assert_net_table`).
  One KiCad write path drops the top-level net table. Everything still opens,
  and the router then routes nothing.
- A pass that runs an optimiser runs `repair_pads.py` after it, every time
  (see CLAUDE.md).
- `route.py` never modifies its `--snapshot`. It copies it over `--board` and
  starts from there.

## Interpreters

A pass imports one of two KiCad APIs, and that decides which Python runs it:

| API | passes |
| --- | --- |
| `pcbnew` (SWIG, KiCad's bundled Python) | add_fiducials, add_keepouts, check_placement, cleanup_pass, export_dsn, export_fab, finish_routes, fix_pad_angles, flip_sides, import_ses, post_route_fix, silk_finish, zones, drc_sample (zone fill), score_route |
| `kicad_tools` (`kct`) | fanout, floorplan, generate_schematic, make_libs, tuck_in |
| neither (text / subprocess) | add_mounting_holes, apply_netclasses, create_pcb, place, repair_pads, erc_check |

`place.py` runs its siblings under `KCT_PYTHON` / `KICAD_PYTHON` for this
reason. `kicad-cli` is invoked as `$KICAD_CLI`, split like a shell word list.

## Coordinates

`board.toml` uses one frame: origin at the outline's **bottom-left**, X right,
**Y up**. KiCad pages run Y down. Convert with `_lib.board_frame` /
`_lib.to_kicad_xy`, and never write a config coordinate straight into pcbnew.

## Checkers

Checkers are passes that write nothing. They report PASS / FAIL / SKIP and
follow one rule for exceptions: an **accepted** item is still measured,
still printed as `accepted:`, and still in the JSON. It is downgraded, never
hidden. **An acceptance that matches nothing is itself a failure**, because a
stale acceptance is a check that succeeds forever. See `accept_blockers` in
`check_placement.py`, and `[[drc.accept]]` / `[[erc.accept]]` in
`drc_sample.py` / `erc_check.py`.

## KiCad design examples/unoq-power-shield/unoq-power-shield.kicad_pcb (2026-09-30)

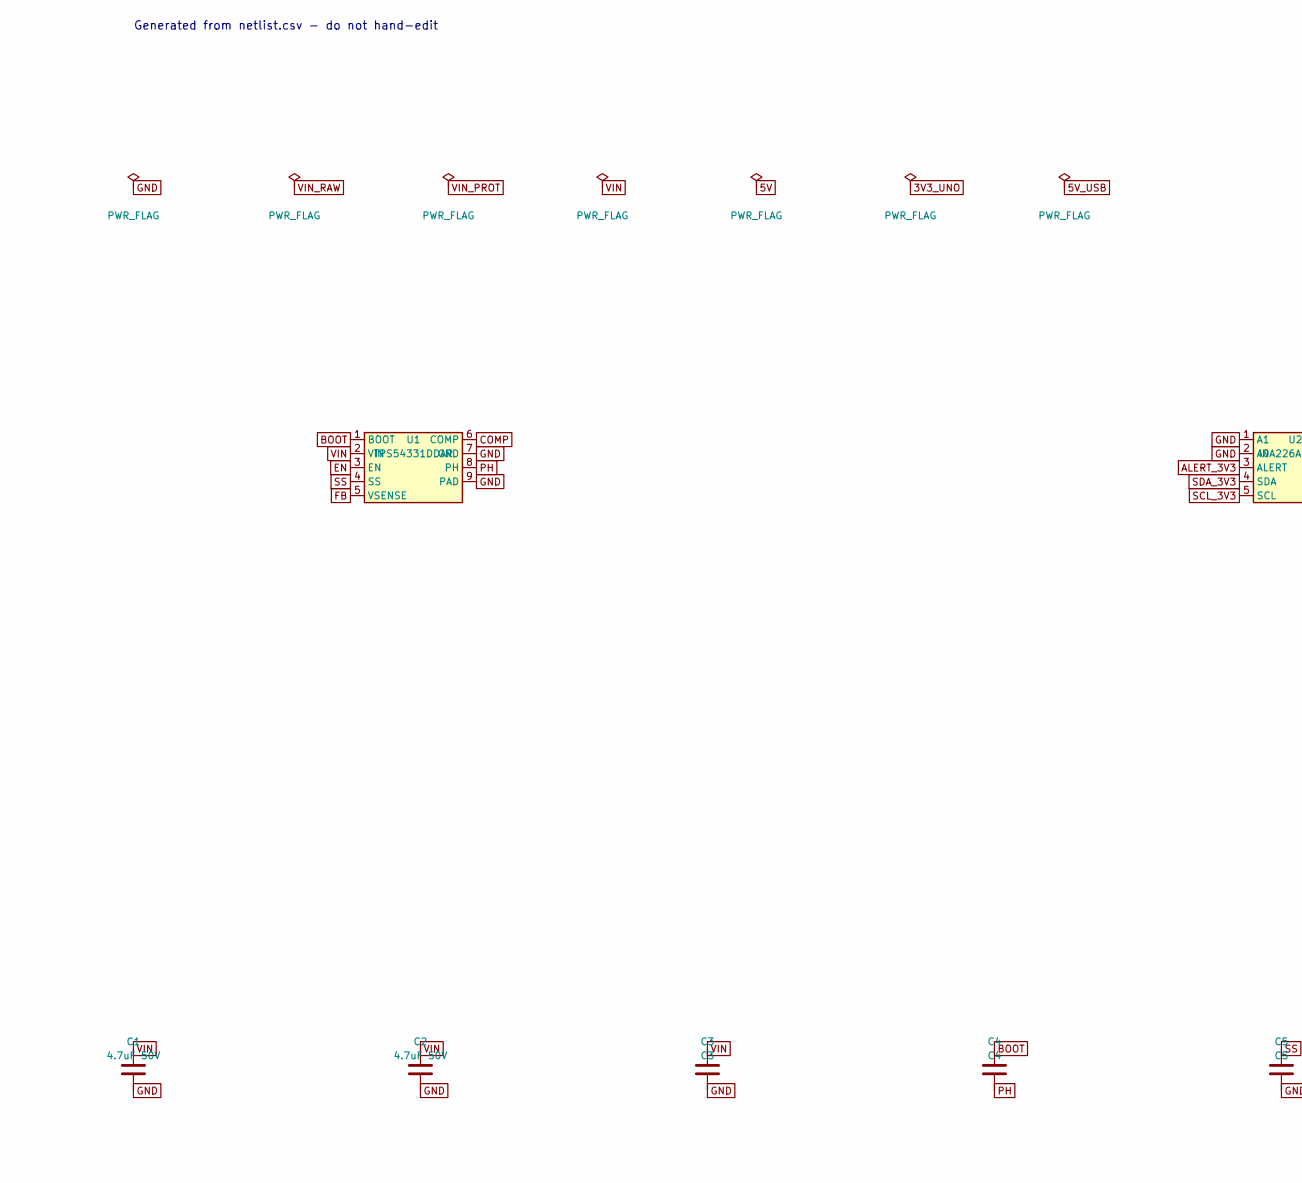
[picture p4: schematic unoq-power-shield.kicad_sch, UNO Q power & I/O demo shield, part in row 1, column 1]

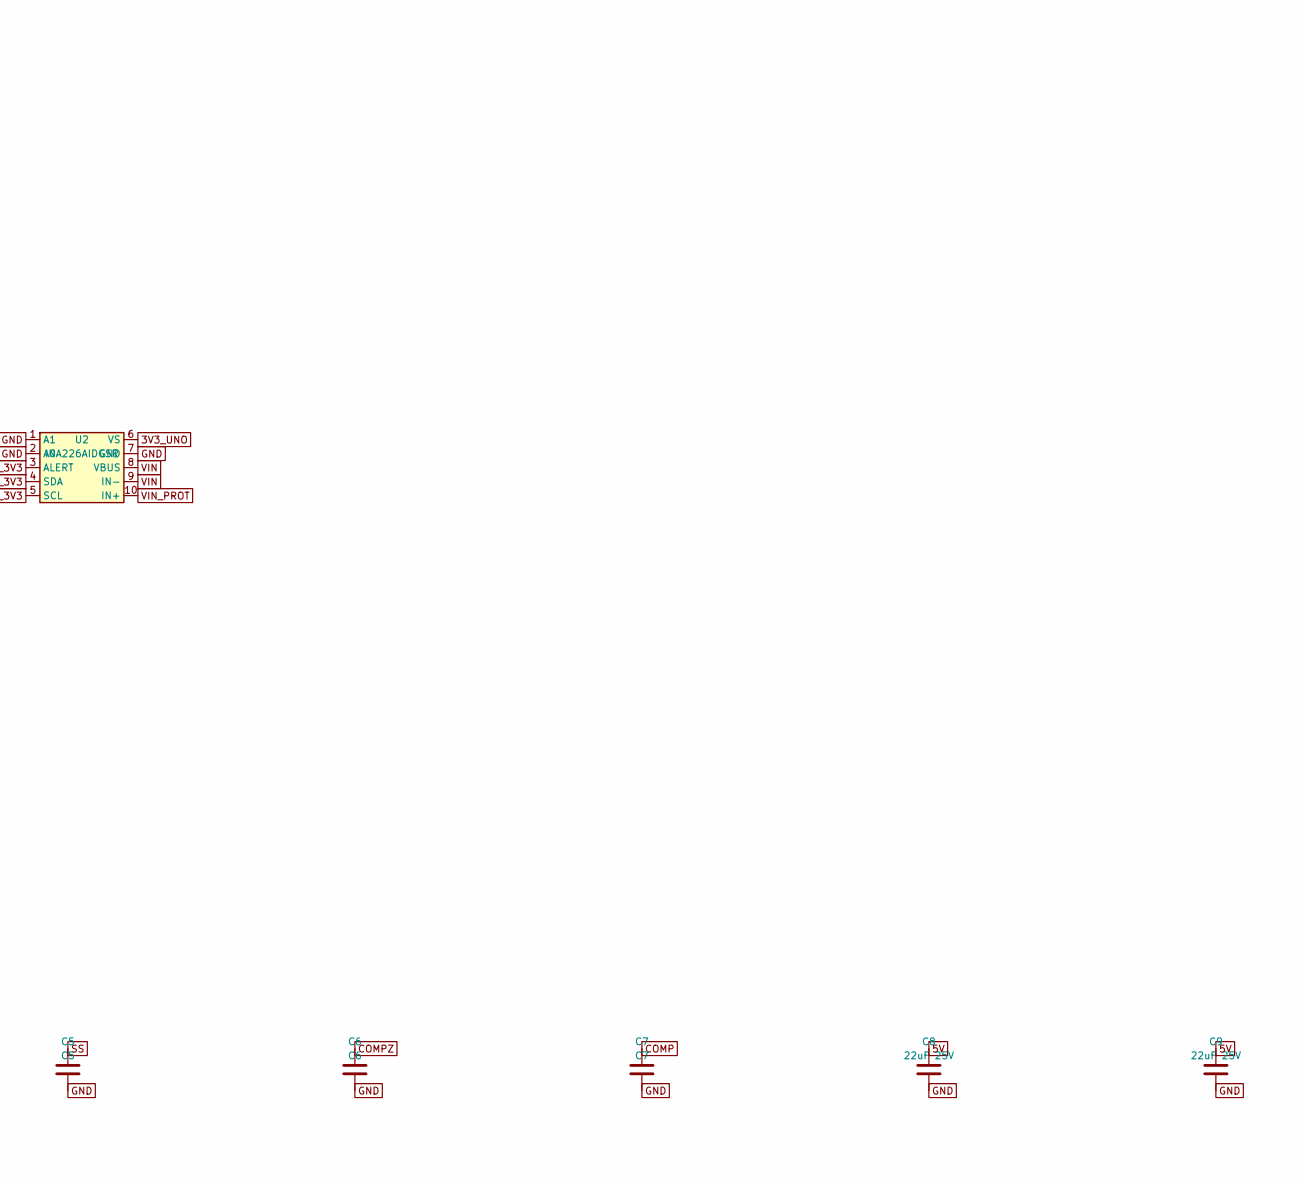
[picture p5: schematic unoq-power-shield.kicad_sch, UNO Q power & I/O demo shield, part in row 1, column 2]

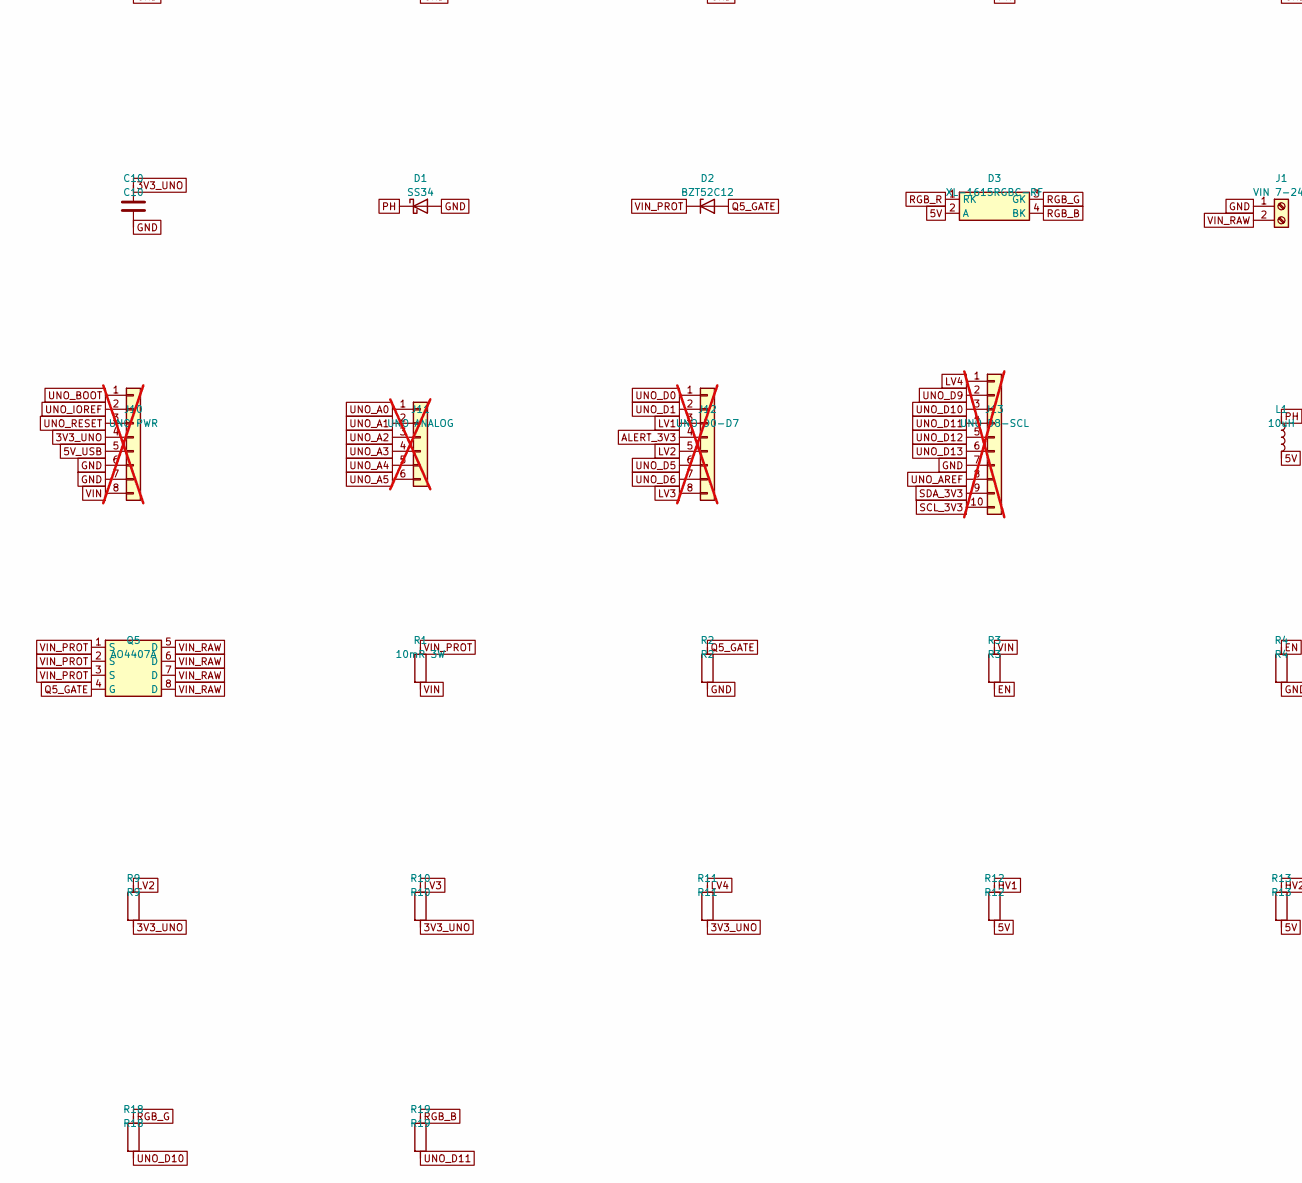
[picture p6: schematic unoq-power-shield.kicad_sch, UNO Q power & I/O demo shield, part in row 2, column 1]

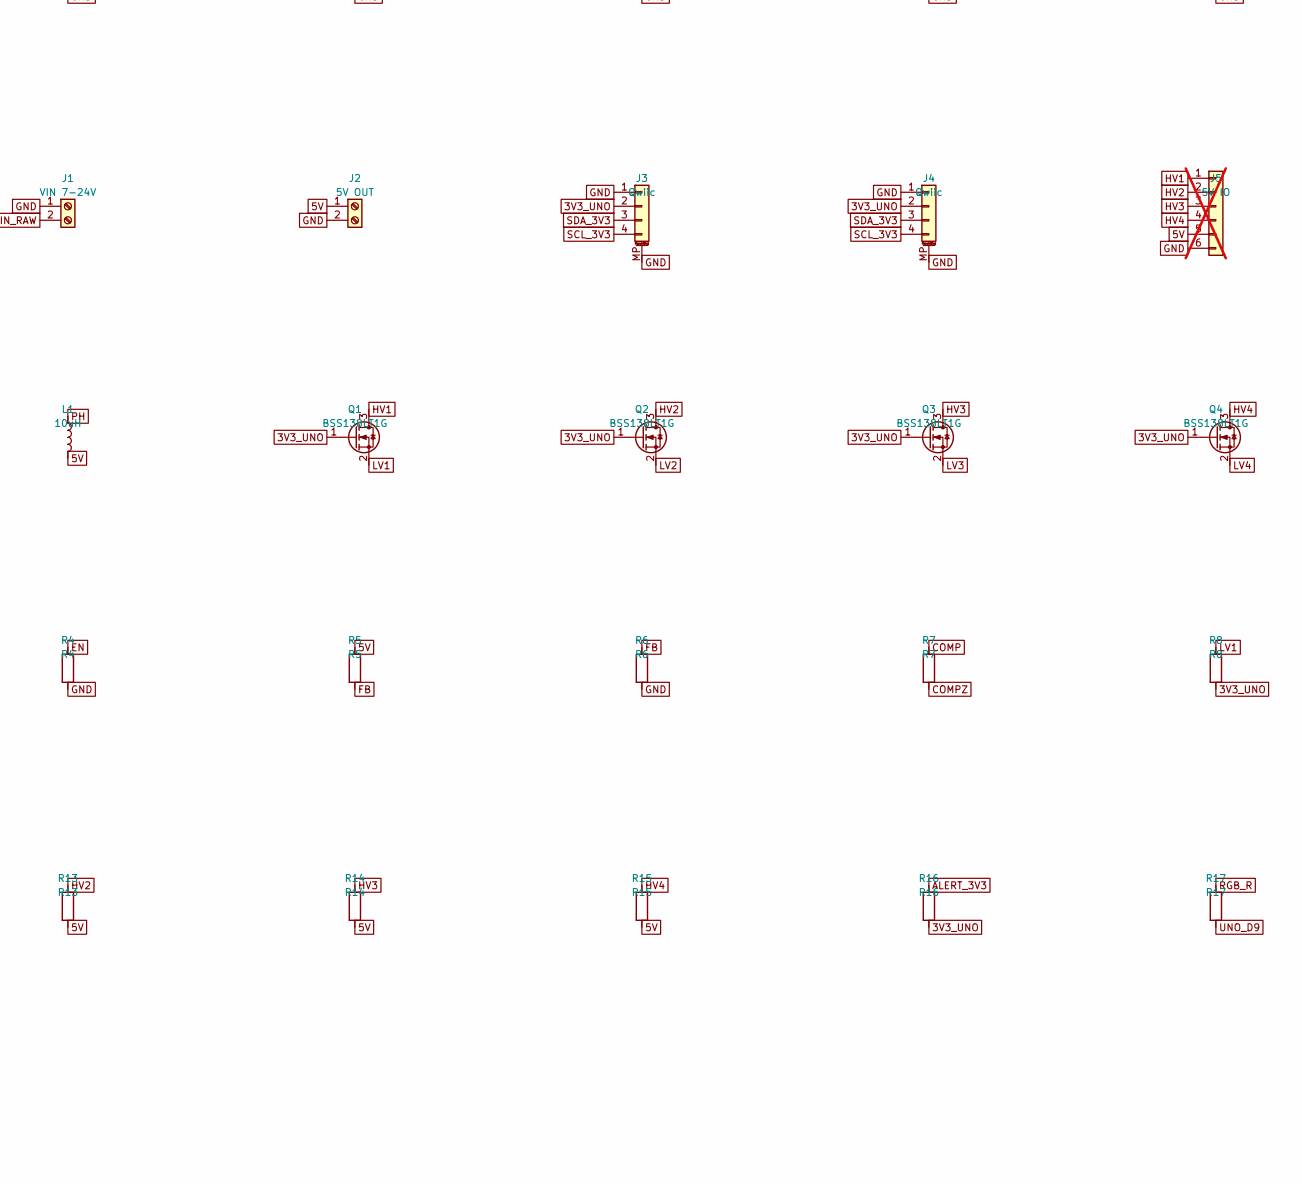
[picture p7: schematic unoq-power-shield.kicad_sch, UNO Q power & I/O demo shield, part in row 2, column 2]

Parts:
C1, C2: 4.7uF 50V; C_1206_3216Metric
C3: C3; C_0603_1608Metric
C4: C4; C_0603_1608Metric
C5: C5; C_0603_1608Metric
C6: C6; C_0603_1608Metric
C7: C7; C_0603_1608Metric
C8, C9: 22uF 25V; C_1206_3216Metric
C10: C10; C_0603_1608Metric
D1: SS34; D_SMA
D2: BZT52C12; D_SOD-123
D3: XL-1615RGBC-RF; XL1615RGBC
J1: VIN 7-24V; KF301_5.0_2P
J2: 5V OUT; KF301_5.0_2P
J3, J4: Qwiic; JST_SH_SM04B-SRSS-TB_1x04-1MP_P1.00mm_Horizontal
J5: 5V IO; PinHeader_1x06_P2.54mm_Vertical; not fitted
J10: UNO PWR; PinHeader_1x08_P2.54mm_Vertical; not fitted
J11: UNO ANALOG; PinHeader_1x06_P2.54mm_Vertical; not fitted
J12: UNO D0-D7; PinHeader_1x08_P2.54mm_Vertical; not fitted
J13: UNO D8-SCL; PinHeader_1x10_P2.54mm_Vertical; not fitted
L1: 10uH; SWPA6045S
Q1, Q2, Q3, Q4: BSS138LT1G; SOT-23
Q5: AO4407A; SOIC-8_3.9x4.9mm_P1.27mm
R1: 10mR 3W; R_2512_6332Metric
R2: R2; R_0603_1608Metric
R3: R3; R_0603_1608Metric
R4: R4; R_0603_1608Metric
R5: R5; R_0603_1608Metric
R6: R6; R_0603_1608Metric
R7: R7; R_0603_1608Metric
R8: R8; R_0603_1608Metric
R9: R9; R_0603_1608Metric
R10: R10; R_0603_1608Metric
R11: R11; R_0603_1608Metric
R12: R12; R_0603_1608Metric
R13: R13; R_0603_1608Metric
R14: R14; R_0603_1608Metric
R15: R15; R_0603_1608Metric
R16: R16; R_0603_1608Metric
R17: R17; R_0603_1608Metric
R18: R18; R_0603_1608Metric
R19: R19; R_0603_1608Metric
U1: TPS54331DDAR; TI_SO-PowerPAD-8
U2: INA226AIDGSR; MSOP-10_3x3mm_P0.5mm

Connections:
ALERT_3V3: J12.4, R16.1, U2.3 (ALERT)
BOOT: C4.1, U1.1 (BOOT)
COMP: C7.1, R7.1, U1.6 (COMP)
COMPZ: C6.1, R7.2
EN: R3.2, R4.1, U1.3 (EN)
FB: R5.2, R6.1, U1.5 (VSENSE)
HV1: J5.1, Q1.3 (D), R12.1
HV2: J5.2, Q2.3 (D), R13.1
HV3: J5.3, Q3.3 (D), R14.1
HV4: J5.4, Q4.3 (D), R15.1
LV1: J12.3, Q1.2 (S), R8.1
LV2: J12.5, Q2.2 (S), R9.1
LV3: J12.8, Q3.2 (S), R10.1
LV4: J13.1, Q4.2 (S), R11.1
PH: C4.2, D1.1 (K), L1.1, U1.8 (PH)
Q5_GATE: D2.2 (A), Q5.4 (G), R2.1
RGB_B: D3.4 (BK), R19.1
RGB_G: D3.3 (GK), R18.1
RGB_R: D3.1 (RK), R17.1
SCL_3V3: J3.4, J4.4, J13.10, U2.5 (SCL)
SDA_3V3: J3.3, J4.3, J13.9, U2.4 (SDA)
SS: C5.1, U1.4 (SS)
UNO_A0: J11.1
UNO_A1: J11.2
UNO_A2: J11.3
UNO_A3: J11.4
UNO_A4: J11.5
UNO_A5: J11.6
UNO_AREF: J13.8
UNO_BOOT: J10.1
UNO_D0: J12.1
UNO_D1: J12.2
UNO_D5: J12.6
UNO_D6: J12.7
UNO_D9: J13.2, R17.2
UNO_D10: J13.3, R18.2
UNO_D11: J13.4, R19.2
UNO_D12: J13.5
UNO_D13: J13.6
UNO_IOREF: J10.2
UNO_RESET: J10.3

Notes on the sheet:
Generated from netlist.csv - do not hand-edit

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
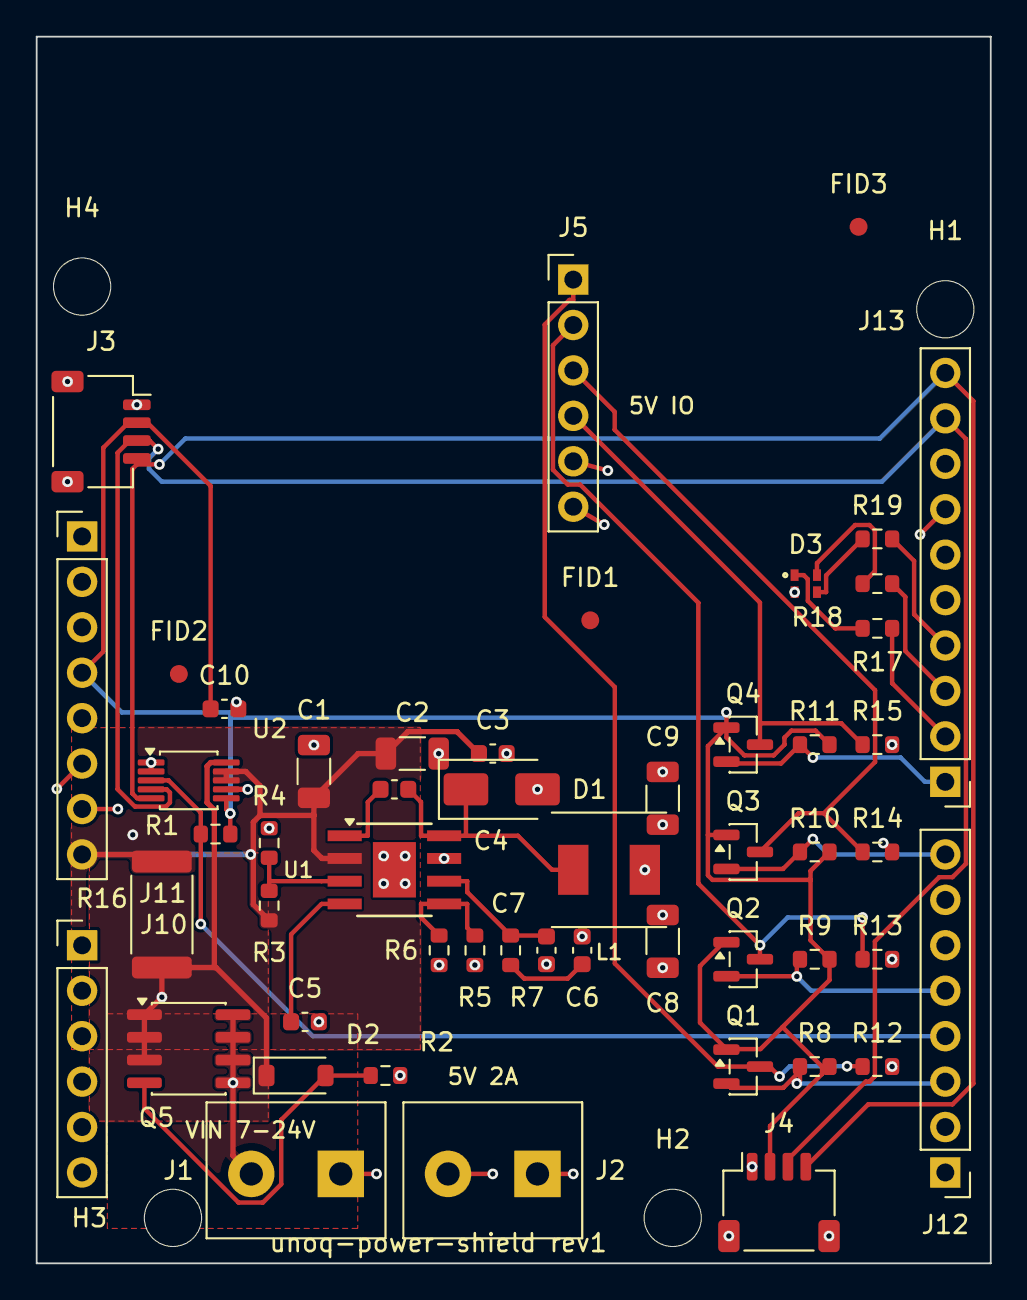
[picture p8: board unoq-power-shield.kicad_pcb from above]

Board: 4 copper layers, 53.3 x 68.6 mm, 56 parts (0 on the bottom side), 31 nets.

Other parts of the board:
FID1, FID2, FID3: Fiducial_pcb-agent
H1, H2, H3, H4: MountingHole_3.2mm

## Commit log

2026-08-30 Restore pcb-agent repo layout from flattened export
    Files arrived as a flat directory (claude.ai export residue in mnt/,
    excluded). Layout re-derived from the paths README.md, Makefile, and
    scripts/doctor.py reference: scripts/, scripts/build/, commands/,
    templates/, tools/. plugin.json moved to .claude-plugin/ per Claude Code
    plugin convention.
    [netlist.csv]
2026-08-30 Containerize the headless pipeline: KiCad 10 + Freerouting 2.3.0 + Temurin 25
    Dockerfile on kicad/kicad:10.0 (digest-pinned) — verified to ship the SWIG
    pcbnew module (10.0.5), importable by arbitrary non-root UIDs. Base is 10,
    not the planned 9: the host KiCad here is 10.0.5 and a KiCad 9 pcbnew
    returns None loading a (version 20260206) board — the exact host/container
    drift doctor.py now warns about. KICAD_BASE build-arg pins back for 9 shops.
    Freerouting pin forced to 2.3.0: 1.9.0 wins the routing-quality A/B but
    throws HeadlessException in -de/-do batch mode (measured), and no X11 goes
    in this image. 2.3.0 is compiled for Java 25, hence Temurin 25.0.4.1+1
    (pinned tarball, sha256-ver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
2026-08-30 UNO Q power shield example: cited plan, board.toml, README (no netlist yet)
    /new-board Phases 1-3 for the example board. Every fact extracted from
    Arduino documents downloaded this session into docs/datasheets/ (CC BY-SA
    4.0, attributed): VIN 7-24 V and 3.3 V logic from the ABX00162 datasheet;
    hole and header coordinates from the T08/T04 blocks of Arduino own NC
    drill file; the Wi-Fi antenna extent measured from their top.art gerber
    (X 0.76-22.1, Y 63.9-68.07 -> keepout 0-26 x 61-68.58); the 2.2k I2C2
    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
2026-08-30 Sync checker: frame assertion, honest summary; add plane_fed; CLAUDE.md rule
    Take the updated validate_gerbers.py (frame/origin check gating every
    coordinate-based rule, summary that counts SKIPs as 'not checked' rather
    than passes) and add the plane_fed exemption: connected CHAINS of thin
    copper on plane-fed nets up to stub_max_mm are pad escapes; longer chains
    are routed runs even when drawn as short segments (endpoint union-find).
    Verified against the rev D2 ordered package: the frame check immediately
    caught that the export lives at (121,-150)-(176,-60) - page coordinates -
    so every absolute-coordinate rule would have inspected empty space; with
    the real frame it matches to 0.000 mm. pl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
2026-08-30 Land build passes (front-end, placement, zones/marks/silk); example netlist
    Ported from the originating project and generalized per CONTRACT.md: every
    pass takes --board/--netlist/--config, strips before rebuilding, emits one
    JSON line, exits non-zero on failure. board.toml grows [build], [libs],
    [parts], [[floorplan.place]], [[zones.pour]], [fanout], [silk] sections
    (documented per-pass). The sacred tool-behaviour guards survive with their
    comments: repair_pads restores rotation as well as position, the net-table
    assertion runs after every board write, fanout checks all four spacings
    including the stub past the next pad's via, silk_finish repositions every
    refdes. kct pinned in the containe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
    [netlist.csv]
2026-08-30 Actually land the build passes: .gitignore's bare 'build/' was matching scripts/build/
    The previous commit's message claimed the passes landed; git had silently
    ignored the entire directory. Root-anchor the transient-output patterns and
    commit the 23 passes, the frame-unification edits (config coordinates are
    board-frame bottom-left Y-up, converted via _lib.board_frame at each
    consumption point), export_fab.py (aux origin pinned to the outline
    bottom-left so gerber/drill coordinates ARE the board frame), the wired
    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
    [netlist.csv]
2026-08-30 GPL-3.0, README sync, frame conversions completed, first-contact fixes
    LICENSE: GPL-3.0 lands with the pcbnew-linking passes, per the plan.
    README: honest status (passes landed, example unproven), the container
    section, gerber-check link (now live at ramalamadingdong/gerber-check,
    MIT), KiCad 9-or-10-matching-your-boards wording.
    Frame unification finished by hand after the agent hit a rate limit:
    floorplan.py flips Y against the outline height; post_route_fix and
    finish_routes convert [[keepouts]] at consumption; zones.py converts pour
    bboxes (kct --bbox is sheet-absolute); silk_finish converts text/lines and
    its keepout-avoidance rects through one abs_pt helper.
    First-contact fixes from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
    [unoq-power-shield.best.kicad_pcb, unoq-power-shield.kicad_pcb, unoq-power-shield.kicad_sch]
2026-08-30 Build chain green end to end; zones survives kct/pcbnew reality
    Three findings from running the full chain, each now encoded:
    - assert_net_table learns pcbnew 10's name-only net dialect (the numbered
    table regex false-alarmed on a healthy 49-net board; zero of BOTH
    dialects is still the disaster it guards against).
    - The pinned kct advertises `zones add --bbox` in its subparser but the
    top-level CLI rejects it, so bounded pours go through pcbnew - created
    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
    [board.1.dsn, pre_route.kicad_pcb, unoq-power-shield.best.kicad_pcb]
2026-08-30 Routing loop closed: xvfb in route.py, DSN sanity, checker interior test
    Four measured fixes from driving the example board through route/check:
    - route.py wraps freerouting 1.9.0 in xvfb-run when headless (the Xvfb
    decision lived only in the Dockerfile; the invocation still died with
    HeadlessException).
    - export_dsn withholds SURFACE pours from the DSN (in-memory only):
    ExportSpecctraDSN writes every zone as a Specctra (plane ...) that
    freerouting treats as fixed copper, so a ground flood on a routable
    layer walls off the whole layer - measured 16 unfinished nets on a
    2-signal-layer board. Plane-layer pours stay: that IS the semantics.
    It also sanitises class names: KiCad 10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
    [board.1.dsn, pre_route.kicad_pcb, unoq-power-shield.best.kicad_pcb]
2026-08-30 Example board: gerber checker green (14/0); idempotency proven byte-for-byte
    Round 4: J5 moved off D3 (its pins run DOWNWARD from pin1 - pin 6 landed
    on the LED and shorted RGB_G to GND), netclass clearance aligned to
    KiCad's 0.2 DRC default end to end (freerouting was routing to the
    bootstrapped 0.15 and every squeeze became a DRC violation), a real
    VIN_RAW pour over the 4 A entry corridor, GND stitching vias on the
    Qwiic mounting tabs.
    The checker now passes the board's own export: 14 passed / 2 not checked
    / 0 failed, with plane_fed exempting exactly the 9 measured pad-escape
    stubs (15.6 mm, all chains <= 3 mm). Run-twice-diff idempotency:
    generate_schematic, floorplan and add_mounting_h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
    [pre_route.kicad_pcb, unoq-power-shield.best.kicad_pcb, unoq-power-shield.kicad_pcb]
2026-08-31 Example board signed off pre-order; add the your-own-board walkthrough
    Example (unoq-power-shield), placement/routing rounds to sign-off:
    - Final state: 0 unconnected and 0 clearance violations across 5
    identical DRC runs; checker 14 passed / 0 failed; ERC clean; all 24
    JLC BOM lines verified in stock. The 17 residual DRC items (3 kinds)
    are each explained in rev-1-plan.md's new ledger - Qwiic edge pads,
    UNO form-factor header/hole adjacency, courtyard grazes.
    - The two structural fixes that ended the recurring PH-past-FB
    clearance cluster: the VIN pour now stops LEFT of U1's pad column
    (as fixed DSN copper it walled off the east corridor and forced PH
    under the chip), and the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
    [bom.csv, pre_route.kicad_pcb, unoq-power-shield.kicad_pcb]
2026-08-31 Add the end-to-end setup guide; point the blog link at what it explains
    docs/end-to-end.md is the whole path in one page: install and the pinned
    container, prove the toolchain on the example board, then an idea through
    /new-board to a fab package. Written for someone who has installed none
    of it.
    Carries the honesty the READMEs carry: Linux/WSL + Docker verified, macOS
    untested, no board fabricated yet, and setup being push-button while
    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
2026-09-02 Add board renders: populated and bare, plus how to regenerate them
    Three kicad-cli renders of the example board — an isometric hero in the
    root README, and a populated/bare pair in the example's own README so the
    board reads as a board before anyone opens a KiCad file.
    Captions carry the same honesty the rest of the repo does: these are
    renders of the design files, no physical board has been fabricated, and
    the populated view shows the stacking headers the assembler does NOT fit
    (they ship DNP).
    img/README.md records the exact commands and the two traps found making
    them, both verified rather than assumed:
    * The container renders come out BARE with no error — the kicad/kicad
    bas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
2026-09-02 Fix four silk markings printing on pads; check for it in the pass
    J5 is the 5 V side of the level shifters (HV1-HV4 + 5V + GND) and its
    label read "3.3V LOGIC" — the wrong rail named on the one connector whose
    entire purpose is that it is NOT the 3.3 V side. It also printed across
    J5's own pads 5 and 6.
    The position bug has a reusable cause: a KiCad connector footprint is
    anchored at PIN 1, not at its body centre. J5's floorplan (30, 55) puts
    pin 1 there and the pads run DOWN to y = 42.35, so a label written at
    y = 44 — chosen to sit ~11 mm clear "below" a header assumed to be
    centred at 55 — landed between pins 5 and 6.
    Adding the check to silk_finish found that two more markings we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
    [unoq-power-shield.kicad_pcb]
2026-09-02 Carry the silk fix into the pre-route snapshot too
    route.py restarts from pre_route.kicad_pcb (`shutil.copyfile(snapshot,
    board)` at step 0), so the snapshot still holding "3.3V LOGIC" on J5's
    pads meant the next `make route` would have silently reinstated the
    defect over the corrected board — with every gate still green, because
    the gates would then be measuring the reverted silk.
    Re-ran silk_finish against the snapshot with the corrected board.toml,
    which is the same pass and order the build uses to produce it (zones ->
    fanout -> fiducials -> keepouts -> silk -> fill -> snapshot). Warnings
    empty; no copper touched.
    [pre_route.kicad_pcb]
2026-09-02 Drop the stray pre_route.kicad_pro pcbnew writes beside the snapshot
    route.py copies only the .kicad_pcb, so the project file pcbnew mints
    next to the snapshot is dead weight. Ignored so it cannot come back.
2026-09-07 Check connector accessibility and keepout copper off the board file
    Two placement facts nothing in this pipeline looked at. A connector you
    cannot plug into was never checked at all; copper in a keepout was checked
    only in the exported gerbers, which is a build, a route and an export away.
    check_placement.py reads the board through pcbnew and answers both in about
    a second, so a floorplan mistake surfaces while the floorplan is still what
    you are editing.
    Connector accessibility measures the gap from each [[connectors]] part's
    mating face to the outline, then sweeps the corridor the plug and its cable
    need, from behind that face out through the edge to mating_depth_mm beyond
    it. Mounting ho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
2026-09-09 Fix the cleanup crash and tell the router the two rules it never had
    Four defects found while driving a 152-part 4-layer board to DRC clean. All
    four were the pipeline lying to itself in some way, which is the case
    CLAUDE.md's rules are written for.
    cleanup_pass segfaulted and threw away everything it had done. BOARD.Remove()
    sets, in its own docstring's words, "the thisdown flag so that the python
    wrapper owns the C++ BOARD_ITEM". After 240 of those the container's wrapper is
    stale, the third GetTracks() comes back as a bare SwigPyObject with no
    __iter__, and the interpreter segfaults at teardown. Because the crash landed
    before SaveBoard, the pass was all-or-nothing: the dedupe, the via r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
2026-09-09 Target the local-clearance rule, and stop necking power escapes to 0.2mm
    Follow-up to the previous commit, all four found by measuring rather than
    reasoning.
    Flooring the GENERAL clearance rule was the wrong shape of fix. It is the
    obvious one -- Specctra cannot express a per-object clearance, so raise
    everything -- and on this board it cost more than it bought: 0.16 -> 0.21mm
    board-wide satisfied U10's ten violations and left TWELVE nets unconnected,
    because a 0.5mm-pitch escape that fits at 0.16 does not fit at 0.21. The
    evidence was there to read: the same board at 0.16 had routed every fine-pitch
    part and had only pour islands open. The nets that need the strict clearance
    are local to t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
2026-09-09 finish_routes: rotate pad boxes; a via was landing ON a rotated part's pad
    The pad inventory used GetSize() unrotated. A rectangular pad on a part at
    90 or 270 has its long axis the other way, so via_site_ok tested the wrong
    rectangle and cleared an escape via sitting ON C38 pad 2 (rot 90) and another
    ON J8 pad 5 (rot 270). One bad axis, sixteen DRC errors: five shorts, five
    mask bridges, three hole-clearance, three clearance. post_route_fix already
    swaps the axes for a ~90 degree pad; this is the same rule one pass along.
    Measured: 16 -> 1 on the same snapshot.
    post_route_fix's island fallback now reaches 8mm, not 3. The islands that
    survive to it are the crowded ones -- and U7 inside baro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
2026-09-09 fanout: power-width escape stubs, and stop losing 0.5mm-pitch parts to one ulp
    derive_target computed via_max = 2*(pitch - clearance - track/2). At a 0.5mm
    pitch with 0.15 clearance and a 0.2 track that is 0.49999999999999994 in
    binary; floor(x*100)/100 made it 0.49, and a min_via_size_mm of exactly 0.50
    -- the board's own DRC floor -- refused the part with "give this part an
    explicit [[fanout.target]]". U6, U7 and U12 silently lost their fanout while
    their neighbours kept it, and the only trace was a note nobody greps for.
    Round to the micron before flooring to the 10-micron grid.
    An escape stub on a POWER pad is now laid at power_track_width_mm rather than
    the target's signal width. At 0.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
2026-09-09 finish_routes: pad extents from the bounding box, not GetSize()
    GetSize() is the ANCHOR of a custom-shaped pad, not its copper. The JST-GH
    mounting-peg pads are drawn from primitives, so a 2.0mm entry_site stub was
    cleared against a box far smaller than the peg and landed 0.021mm from it.
    The bounding box is the copper for every shape, rotated or not, so it replaces
    both GetSize() and the rotation swap from the previous commit; it is
    conservative on a 45-degree pad, which is the right direction. Measured: the
    J7 peg graze is gone and no via has landed on a foreign pad since.
    Claude-Session: https://claude.ai/code/session_01Tjo8iCk62hZ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
2026-09-09 finish_routes: strip router segments that graze a foreign via, then re-complete
    Freerouting lays the odd track 20-90um closer to a PRE-PLACED via -- a fanout
    escape, a stitching via -- than its own rule, and which net it picks moves run
    to run: CAN4_H, then EVK_5V_IN, then EN_BUCK. A nudge tool cannot fix it: the
    shortfall exceeds the nudge budget and the via is fixed by design. This pass
    can. The segment is stripped in step 0 alongside the ring-violators, the net
    falls into the completion set, and the A* re-lays it through path_ok at the
    real clearance. Deterministic, and it uses copper this pass already knows how
    to place. Snapshotted before the first Remove(), same as the ring strip.
    Co-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
2026-09-09 finish_routes: graze repair measured the way DRC measures
    The step-0 strip now covers router segments grazing a foreign PAD as well as
    a foreign via, and stub_ok checks its stubs the same way. Getting there was
    three wrong geometry models in a row, each caught by measuring:
    * max(bbox, GetSize()) per axis put the rotation bug back in the other
    axis -- a rotated MSOP pad's box came out 3.0mm wide for 0.35mm of
    copper. 89 segments stripped, 62 nets unconnected.
    * projecting the pad centre onto the segment and taking a Chebyshev
    distance is wrong by up to 2x on a 45-degree approach. 74 legal power
    tracks read as 0.05mm from 0402 GND pads.
    * an exact segment-to-box distanc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
2026-09-09 finish_routes: half a cell of margin on the completion grid
    The A* walks cell centres, and an obstacle is marked only where a centre
    falls inside it, so a path can hug a via by up to GRID/2 -- 0.125mm at the
    default 0.25 -- closer than the inflated radius says. Measured: a completion
    link on In2 landed 0.1275mm from a fixed fanout via against a 0.15mm rule,
    the last DRC error on the board. Every other check in this pass is exact
    now; the grid was the one place quantisation could still leak.
    Same snapshot, 5 DRC samples: 1 violation -> 0.
    Claude-Session: https://claude.ai/code/session_01Tjo8iCk62hZ3urh82kaeah
2026-09-10 run.sh: mount an out-of-tree board directory at /board
    PCB_AGENT_BOARD points at a board kept in its own repository; the
    container sees it at /board so `make build BOARD_DIR=/board` works
    without copying the board into this tree. Unset, nothing changes.
2026-09-25 direct_connect: Direct netlist column places parts pad-on-pad
    A new optional Direct column in netlist.csv tags one pin of a part. The
    pass finds the other pins already on that net and places the part with
    that pad overlapping one of them (overlap_mm), trying each target pad,
    all four sides and all four rotations as measured by pcbnew. A pose is
    rejected if it breaks clearance to another net, puts a pad under the
    target's body, or runs off the board. Poses that collide with another
    part fail with an actionable message. The saved board is then reloaded
    and each pair is checked for the same net and touching copper.
    Runs twice: --stage pre, before place.py, handles tags with an anchored
    target,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
    [netlist.csv]
2026-09-25 test_direct_connect: netlist, geometry and pcbnew board tests
    Netlist parsing and rejection paths, candidate geometry, and four board
    cases run through the real pass on a pcbnew-built board (INA226 MSOP-10
    plus an 0603 with the example library's pad geometry). Results are judged
    by kicad-cli DRC: held (pre, post, post stay byte-identical; pads
    connected), free (pre defers, post places, stable), blocked (exit 1, board
    untouched), and flipped (the real flip_sides sends the target to B.Cu and
    the part follows). The board half reports SKIP without pcbnew.
    Checked against KiCad 9.0.9. Pushing the pads 0.1 mm apart instead of
    overlapping fails 6 tests, including the DRC connectivity check.
    Co-Au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
2026-09-30 Gate DRC/ERC, check connector orientation, add review renders
    Cross-checked against paul356/KiCad-AI-Assistant. Most of that repo edits
    KiCad files directly and runs its own router, which this repo's rules
    forbid, so what came across is ideas, not code. The gaps the comparison
    exposed here mattered more.
    Gates (levels 0-2 now fail instead of report):
    - drc_sample.py: DRC x5, fails on any error not in the board.toml
    [[drc.accept]] ledger, any unconnected item, connectivity parity
    (KiCad ships net_conflict as a warning), GUI exclusions, and stale
    ledger entries. route.py uses it; `make check` runs it on a filled copy.
    - erc_check.py: ERC in `make check`, same ledger rules.
    - export_fab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
2026-09-30 Fix finish_routes redundant copper; make out-of-tree builds work
    First end-to-end run in the pcb-agent container (WSL) on a scratch copy
    of the example.
    finish_routes: clusters_for never unioned a segment's two endpoints, so
    every routed net with a segment longer than its width looked broken.
    pcbnew counted 0 missing links before the pass; it still worked 26 nets,
    laid 98 redundant links and reported 14 as NO PATH FOUND. Fixed. On the
    example rebuild: 492 -> 294 segments, 123 -> 54 vias, 1536 -> 913 mm of
    track, 82 -> 2 off-45 segments; DRC x5 identical (17 ledgered errors,
    0 unconnected). route.py now records pcbnew's count just before the pass
    and warns when the pass works nets pcbnew cal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
2026-09-30 drc_sample: accept Direct pad-on-pad pairs from netlist.csv
    direct_connect (from master) places Direct-tagged parts pad-on-pad, and
    DRC reports every such pair as courtyards_overlap. The DRC gate now reads
    the Direct column (direct_connect.load_tags) and accepts a
    courtyards_overlap between a tagged part and one of its own candidate
    targets, printed as "accepted (Direct)". Any other overlap still fails.
    Tested on the example: C8 tagged Direct=L1 passes without a ledger entry;
    the same board untagged fails naming C8/L1. test_direct_connect.py: 0
    failures on this branch.
2026-09-30 Makefile: stop taking NAME from the environment; narrow redundancy warning
    WSL exports NAME (the machine's name) into every shell, and `NAME ?=`
    took it: an in-place build of the example named its files
    PowerHouse.kicad_pcb and wrote a second drill set into fab/. `NAME =`
    keeps a command-line NAME=... working and ignores the environment.
    finish_routes now emits stripped_nets (nets its own graze/ring strips
    cut) and nets_worked. route.py's redundant-copper warning fires only for
    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
2026-09-30 Example: rotate J4 to face its edge, rebuild; all gates pass
    J4 (Qwiic, SM04B-SRSS-TB) was at rotation 180 with its socket opening
    into the board. Floorplan now rotation 0, y 3.2 -> 3.4 so the MP tabs
    clear the 0.5 mm edge rule by 0.625 mm; the J4 copper_edge_clearance
    ledger entry (a symptom of the rotation) is removed.
    Rebuilt from netlist.csv in the pinned container (KiCad 10.0.5,
    Freerouting 1.9.0) with the fixed pipeline. make check passes:
    ERC 0 errors; pad angles all correct; DRC x5 13 errors, all ledgered,
    identical every run, 0 unconnected, no stale entries; check_placement
    11/0; validate_gerbers 15/0 with IPC-D-356 = netlist.csv 159/159.
    drc_report.json, erc_report.json and img/*.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
    [pre_route.kicad_pcb, unoq-power-shield.kicad_pcb, unoq-power-shield.kicad_sch]
2026-09-30 place: skip the optimiser when every part is anchored
    The example anchors all 49 parts, so kct optimize-placement had nothing
    to move and, handed a layout carrying ledgered courtyard grazes, exited
    "infeasible placement" in every round: four FATALs per build, board
    unchanged. place.py now counts free parts (board refs minus floorplan,
    hole and anchor refs, read as text since this pass may run without
    pcbnew; zero refs found is a failure) and with none free runs only
    repair_pads, tuck_in, the conflict score and fix_pad_angles, reported
    as skipped="all parts anchored".
    Measured on a scratch rebuild of the example: 0 FATALs; repair_pads
    restored 16/53 footprints straight off the floorplan (the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
